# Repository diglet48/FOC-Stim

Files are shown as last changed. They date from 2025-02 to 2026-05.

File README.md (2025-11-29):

FOC-Stim is a family of next-generation estim devices that generate current-controlled analogue waveforms.
It can be controlled with [Restim](https://github.com/diglet48/restim).

Unlike traditional devices, the FOC-Stim has no channels
but offers an any-to-any output topology.

# Version 1

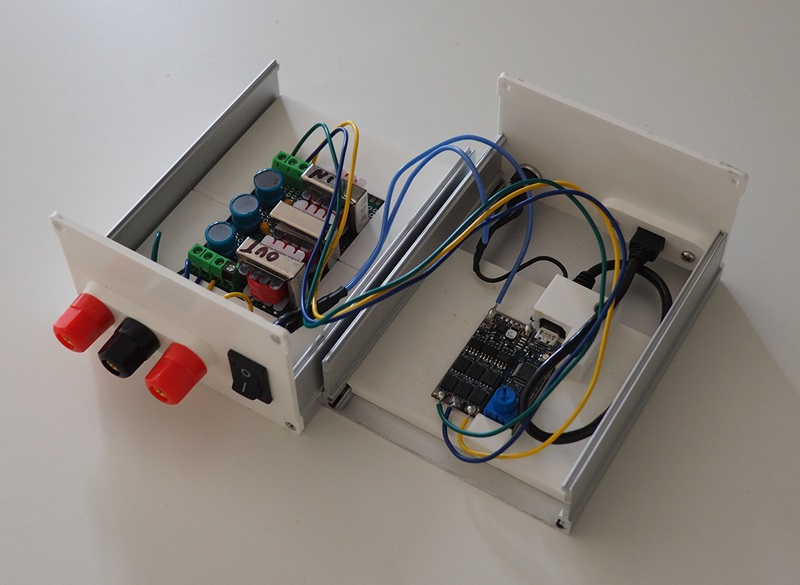
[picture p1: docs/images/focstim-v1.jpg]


Version 1 has 3 outputs. It uses a three-phase motor drive development kit from ST (the [B-G431B-ESC1](https://www.st.com/en/evaluation-tools/b-g431b-esc1.html)) for control. It only support three-phase output.

It is fairly easy to build with basic soldering skills, all parts can be ordered from mouser. For more information see [docs/focstim-v1.md](docs/focstim-v1.md)

# Version 4

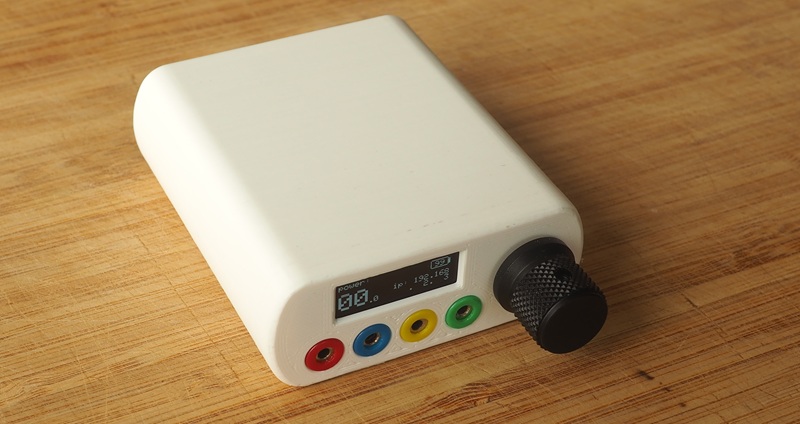
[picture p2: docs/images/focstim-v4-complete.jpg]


Version 4 uses a custom PCB. It improves the original by adding one extra output, a battery, and wireless comms.

See [docs/focstim-v4](docs/focstim-v4.md) for more info.

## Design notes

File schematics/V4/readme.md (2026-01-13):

You can order assembled boards from JLCPCB

## Mainboard
* Single-sided assembly (PCBA type standard, not economic)
* Select lead-free HASL finish.
* Verify the rotation of all chips and diodes against the reference image. The initial placement usually has U11 oriented wrongly. 

## Frontpanel
* Single-sided assembly (PCBA type economic) OR no assembly
* Select lead-free HASL finish.

You can choose to let JLCPCB assemble the SMD nuts and 2.0mm headers,
the error rate for letting users solder these components at home is
surprisingly high.

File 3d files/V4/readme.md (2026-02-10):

# Print instructions

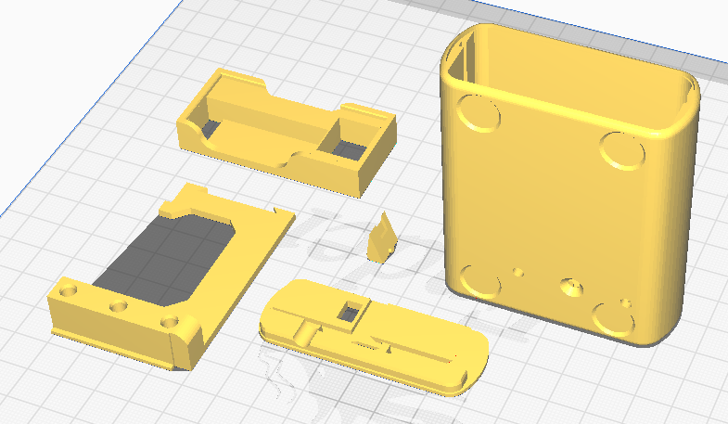
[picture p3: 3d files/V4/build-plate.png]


No supports needed when printing at 0.2mm layer height.

When printing the case, align seams on the bottom.

Rear panel with 0.0mm clearance is a snap fit on my printer.

Display spacer is optional in case you have problems with the display
bending, it can be jammed behind the display.

# Extra prints

`extras/switch clip` a clip designed to fit in the nintendo switch leg strap,
for wearing the device on your leg. Designed for M3x8 countersink.

`extras/rear panel exp` a modified rear panel with a cutout for 2x5 1.27mm connector,
can be used to break out the expansion header with a standard 10cm SWD cable.

# Changelog

* 10/02/2026 Increase PCB rail clearance from 0.2mm to 0.3mm
* 08/01/2026 Modified rear panel for V4.2 (1 capacitor moved)
* 29/11/2025 Initial release for V4.1 PCB

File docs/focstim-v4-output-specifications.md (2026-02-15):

# Introduction

The maximum output the FOC-Stim V4 can deliver depends on the skin resistance.

With which skin resistance can the device still blow your socks off?
The answer is approximately $500 \Omega$.

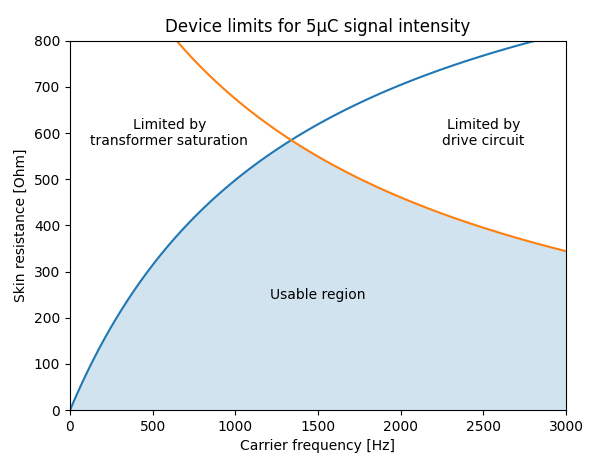
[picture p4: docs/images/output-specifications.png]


# Skin resistance?

I like using the skin resistance instead of the body resistance,
as the basic concept of body resistance starts to become fuzzy with more
than 2 electrodes. In most cases, skin resistance * 2 = body resistance.

I collected some data under various circumstances:

| skin resistance<br/>(one-way) | example |
|---:|---|
| 25 Ω | Large metal insertable |
| 50 Ω | Electro-rings (metal) |
| 100 Ω | Double-wrap of 8mm conductive rubber<br/>below balls |
| 140 Ω | Glans loop with 8mm conductive rubber,<br/> 3x3cm rubber pad |
| 200 Ω | Year-old rubber loops, regularly used |
| 250 Ω | Industry standard testing value,<br/> 3x3cm sticky pad |
| 500 Ω | ? |
| 1000 Ω | mystim brand conductive rubber insertables |

Most electrodes fall well within the usable region.

# Appendix

## Assumptions

The Xicon 42TL004 is limited to $`7500 V*\mu s`$ output before complete 
saturation, in practice $`6000 V*\mu s`$ is about the max for
undistorted waveforms. The winding ratio is 5.5.

The FOC-Stim V4 drive circuit is limited to $30V$. For technical
reasons, the effective voltage-to-neutral is a bit less than half that,
I use a conservative limit of $10V$. This results in an output-to-output
voltage of $110V$.

The maximum signal intensity I use is a bit less than $5\mu C$. 
I used this number as a benchmark.

The FOC V4 boost circuit can deliver about 4W of power. 
This is assumed to be not a limitation.

The device $\frac{dI}{dt}$, current sense range, control loop bandwidth
and transformer specifications all start to become problematic around
$3000Hz$ to $5000Hz$.

Time constant of the nerves is $355\mu s$

## Math

$Q_0 = 5 \mu C$, the maximum tolerable signal intensity.

$Q_t = Q_0 \times (1 + \dfrac{\text{pulsewidth}}{355\mu s})$, the amount of charge we 
actually have to deliver to get the maximum signal intensity.

$Q_t = \pm \dfrac{I_{\text{peak}}}{2 \times \pi \times \text{frequency}}$, minimum and maximum charge in sine wave signal.

$R = \dfrac{Vs}{Q_t}$, link transformer saturation to resistance and charge.

$R = \dfrac{10V \times \text{winding ratio}}{I_{\text{peak}}}$, ohms law assuming inductance is negligible. 

It follows that the maximum resistance before we run into 
transformer saturation is:

$R = \dfrac{6000V\mu s}{5\mu C \times (1 + \dfrac{1}{2 \times \text{frequency} \times 355\mu s})}$

And the maximum resistance before the drive circuit maxes out is:

$R = \dfrac{10V \times \text{winding ratio}}{5\mu C \times \pi \times (\text{frequency} \times 2 + \frac{1}{355\mu s})} - \text{drive circuit resistance}$

The drive circuit resistance is about $1.75 \Omega \times \text{winding ratio}^{2}$

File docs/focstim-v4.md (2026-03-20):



Schematics, PCB and case design by Sekizen.  
Software by Diglet.

# Specifications

* Three and four-phase output capability.
* 7-hour battery life with typical electrodes.
* Wireless communication (Wifi).
* Small display for diagnostics, knob for volume adjustments.
* Built-in accelerometer.
* Optional external sensors for nogasm/edge-o-matic functionality.

# Useful pages

* [Schematics / Gerbers](/schematics/V4/readme.md)
* [Bill of materials](focstim-v4-BOM.md)
* [3D files](/3d%20files/V4)
* [Assembly guide](focstim-v4-assembly.md)
* [Flashing your board](focstim-v4-flashing.md)
* [AS5311 sensor](as5311%20sensor.md)

# Nerd zone

* [Output specifications](focstim-v4-output-specifications.md)

# Changelog

## V4.3
Replace C6 (SYSSense) and C20 (VMSense) from 100nF to 10nF.  
Improve thermal relief on some hard-to-solder ground pads on mainboard and frontpanel.

## V4.2
Added LSM6DSOX 6-DOF IMU.  
Added cutout for ESP32 antenna.  
Change the part number of the boot buttons to save space.  
Change the part number of the boost inductor due to parts shortage.  
Add ground spokes to some solder pads.  
Modified board outline to reduce abrasion on frontpanel.

## V4.1
Initial public version.  
Changed most pin assignments on the ESP32.  
Adjust switch circuit to avoid inrush current killing the TSP631000.  
Modify frontpanel dimensions for extra creepage/clearance.  

## V4.0
Not publicly released, switched to DRV8231A drivers.

## V3.0
Not publicly released, based on MAX22213 drivers.

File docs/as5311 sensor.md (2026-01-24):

The FOC-Stim V4 has support for an erection sensor based on the AS5311.

Get the 3D files here: https://github.com/diglet48/toy-designs/tree/main/omega%20clamp

To construct this sensor and attach it to your FOC-Stim, you need these parts:

* modified rear panel [found in extras](/3d%20files/V4/readme.md).
* ams OSRAM AS5311-TS_EK_AB sensor board. 
* 3.3cm of magnet strip https://aliexpress.com/item/1005002805940724.html
* jtag breakout board https://aliexpress.com/item/1005004180810695.html
* 10cm 1.27mm 2x5 flatcable, for inside the box. https://aliexpress.com/item/1005008046702049.html
* 50cm 1.27mm 2x5 flatcable, male to female. https://aliexpress.com/item/1005006350473754.html
* 1.27mm 2x5 IDC header socket https://aliexpress.com/item/1005010396002233.html

# Build instructions

Embed your 10mm cable inside the rear panel like this. 
Inside the box, it will connect to the header marked "EXPD".

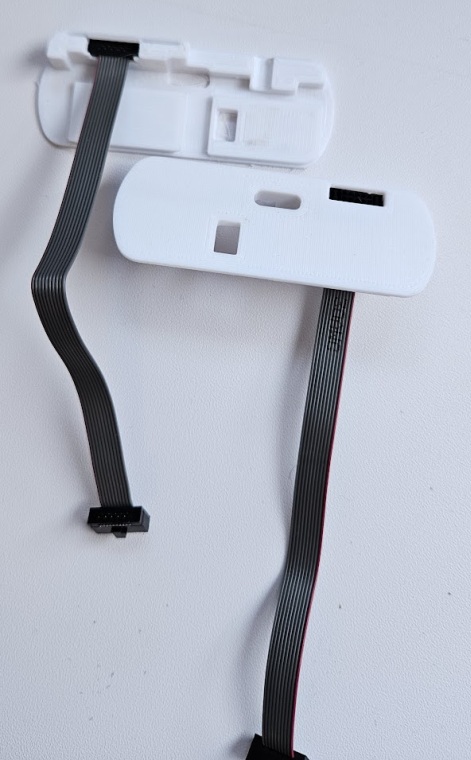
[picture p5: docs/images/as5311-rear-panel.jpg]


Cut off part of the 50cm flatcable and swap wires 1/2, 3/4, 5/6, 7/8, 9/10.
Then crimp on a new header.

This needs to be done because the male-to-female cable mirrors the pins. It
is not needed if you plug the sensor with a simple female-to-female cable
directly into the mainboard.

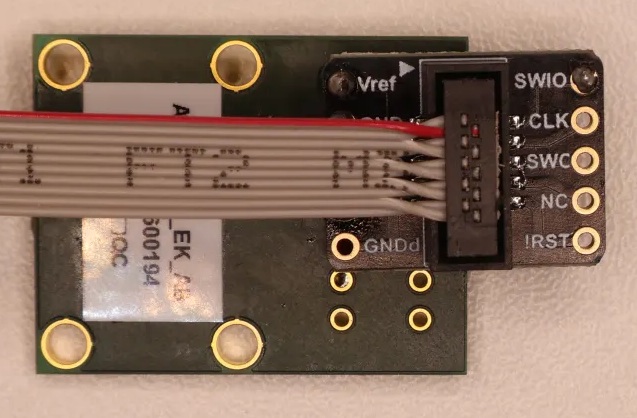
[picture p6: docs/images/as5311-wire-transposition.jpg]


Solder the breakout board with 4 2.54mm pins to the sensor.

Connect the line of (four) pins "vref, gnd, gnd, key" on the breakout board to
"gnd, DO, CLK, CSn" on the AS5311. Then use a small piece of wire to bridge
SWO to both 3v3 and 5v.

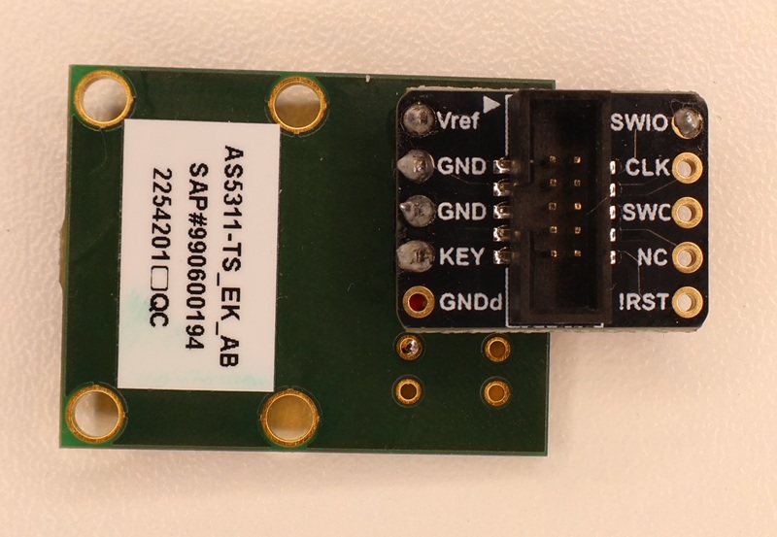
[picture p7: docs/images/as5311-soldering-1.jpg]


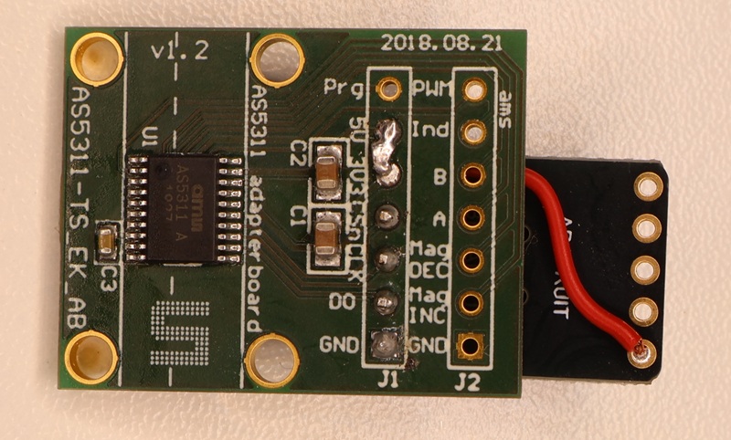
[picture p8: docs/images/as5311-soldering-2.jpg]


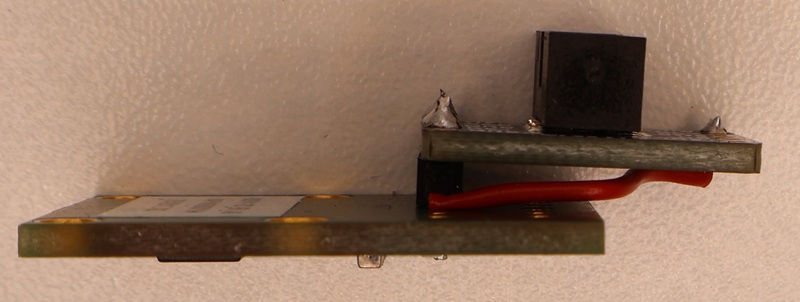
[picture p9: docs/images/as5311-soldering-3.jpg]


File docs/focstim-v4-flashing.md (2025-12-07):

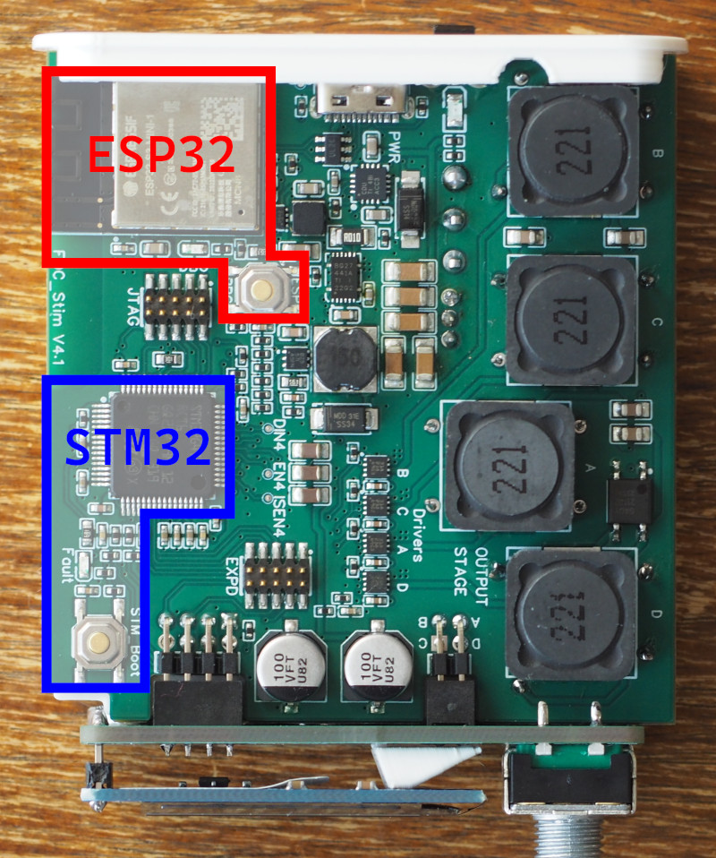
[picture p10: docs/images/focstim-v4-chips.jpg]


The FOC-Stim V4 contains 2 chips that need software to work, an ESP32 and STM32.

Only the switch is required to be soldered before flashing.

# The easy way

The first time flashing the board, you will need to hold the boot
button next to the respective chip while flipping the power switch.
This puts the chip in firmware update mode.

ESP32: Use the webflasher at https://github.com/diglet48/FOC-Stim-esp32-Webflasher

STM32: Start Restim, use tools -> firmware updater. Download firmware binary here: https://github.com/diglet48/FOC-Stim/releases

# Development

Development for both chips is done with Visual Studio Code.
Install the plugins PlatformIO and optionally Teleplot.

## ESP32

Get the code here: https://github.com/diglet48/FOC-Stim-esp32  
Make sure the correct environment is selected. (`focstim_v4_1` or `focstim_v4_0`).
Click the `upload` button in the sidebar.

V4.0 and V4.1 are not compatible.

## STM32

Get the code here: https://github.com/diglet48/FOC-Stim  
Make sure the correct environment is selected. (`focstim_v4`).

Use Restim or attach a debugger to upload the code to the board.

V4.0 and V4.1 use the same STM32 firmware.

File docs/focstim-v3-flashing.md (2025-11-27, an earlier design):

> [!CAUTION]
> Only applicable to FOC-Stim V3, not V4 or later.

# Soldering

* 4x transformers
* 4x 4mm bullet connectors (red, blue, yellow, green)
* 1x potmeter (optional)
* 1x jst-ph 2.0mm (optional, for battery. No reverse voltage protection!!!)

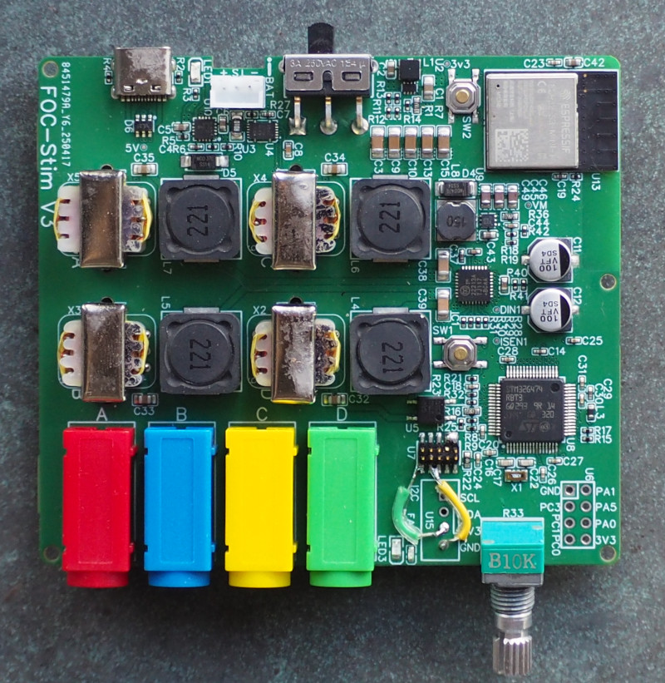
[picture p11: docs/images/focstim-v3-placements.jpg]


# Flashing the ESP32

All V3 boards I sent out came with the ESP32 firmware pre-programmed.

# Flashing the STM32 (serial)

Due to various hardware bugs, the STM32 crashes on boot. Extra steps are needed to boot normally or enter the bootloader.

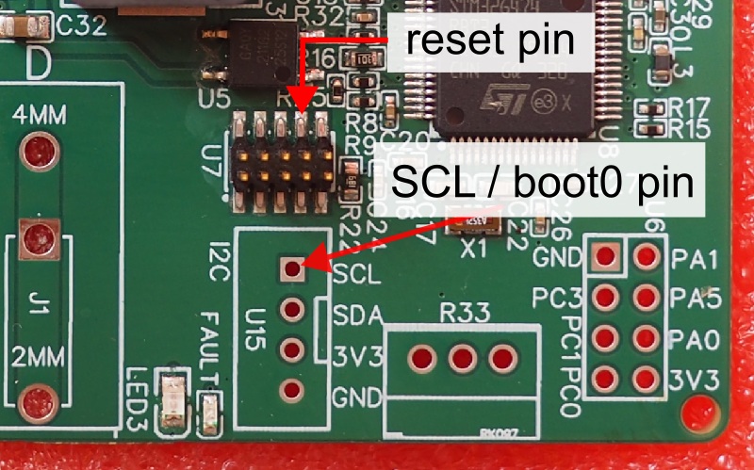
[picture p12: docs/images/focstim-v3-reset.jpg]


**To enter the bootloader:** turn on the power, then briefly short the reset pin to ground.

In the bootloader, the following actions can be performed with the STM32CubeProgrammer CLI:

Erase the flash: `.\STM32_Programmer_CLI.exe -c port=COM4 -e all`

Program the firmware: `.\STM32_Programmer_CLI.exe -c port=COM4 -d firmware.elf`
(`.hex` also works. `.bin` does not work)

Start the firmware: `.\STM32_Programmer_CLI.exe -c port=COM4 -g 0x08000000`

Using the GUI to program the board will often fail.

**To start the board:** short the SCL / Boot0 pin to ground before flipping the power switch. If done succesfully, one of the LEDs will turn on.

# Flashing the STM32 (jtag debugger)

Ensure your V3 board has the required patches.

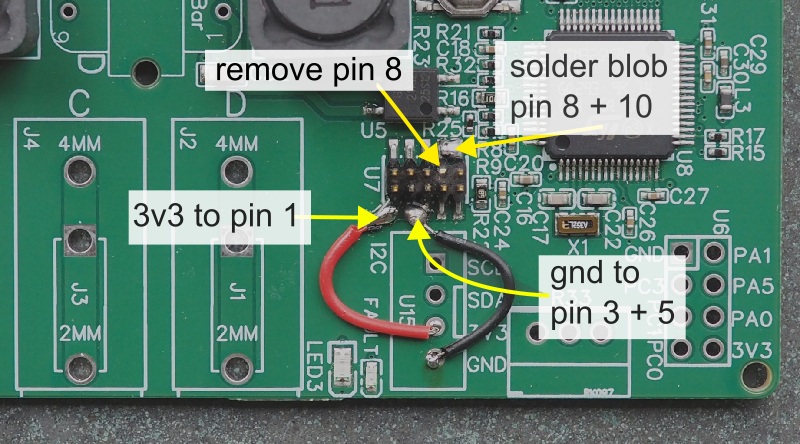
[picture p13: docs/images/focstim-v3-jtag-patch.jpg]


Upload the .elf firmware using your debug probe. I use segger J-Link with ozone debugger, but STM32CubeProgammer works too.

A hardware bug prevents the firmware from starting normally. Use one of these methods to start the firmware:
* Use the ozone debugger to 'reset program to main (F4)'.
* Short the SCL pin to ground, then reboot the board by shorting the reset pin or flip the power switch.
* Use STM32CubeProgrammer to set option bit `nSWBOOT` to 0. You can then boot the board normally. Only do this if you have a debug probe!

# Battery

To run the system from battery, the fuel gauge first needs to be programmed. The firmware does this on boot, provided you did not short SCL / Boot0 to ground.

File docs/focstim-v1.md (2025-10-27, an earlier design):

# Hardware

For component selection, refer to the [Bill of materials](/docs/focstim-v1-BOM.md).

How to wire:



`U`, `V`, `W` are the 3 outputs on the board, with `U` being the one closest to the potentiometer.

The side of the transformer marked with black sharpie should be connected to the board-side.
The primary, indicated with a "P", is the output side.

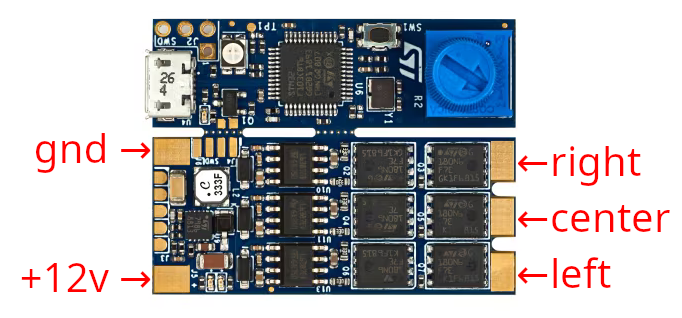
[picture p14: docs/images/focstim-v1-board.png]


The build on a breadboard:

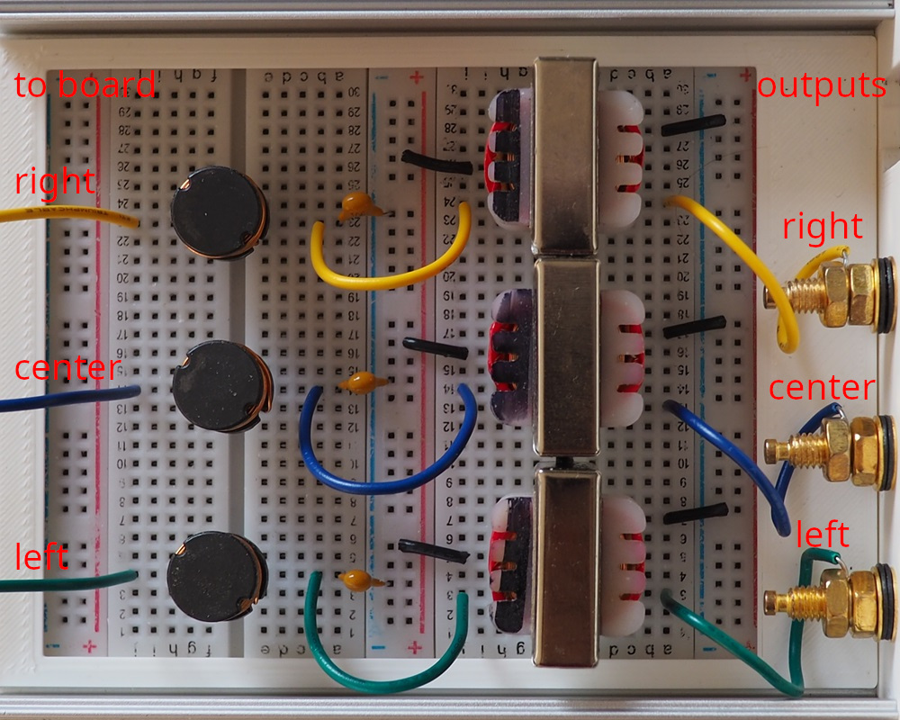
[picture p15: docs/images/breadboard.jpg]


Complete build built into 120x97x60mm aluminium enclosure.

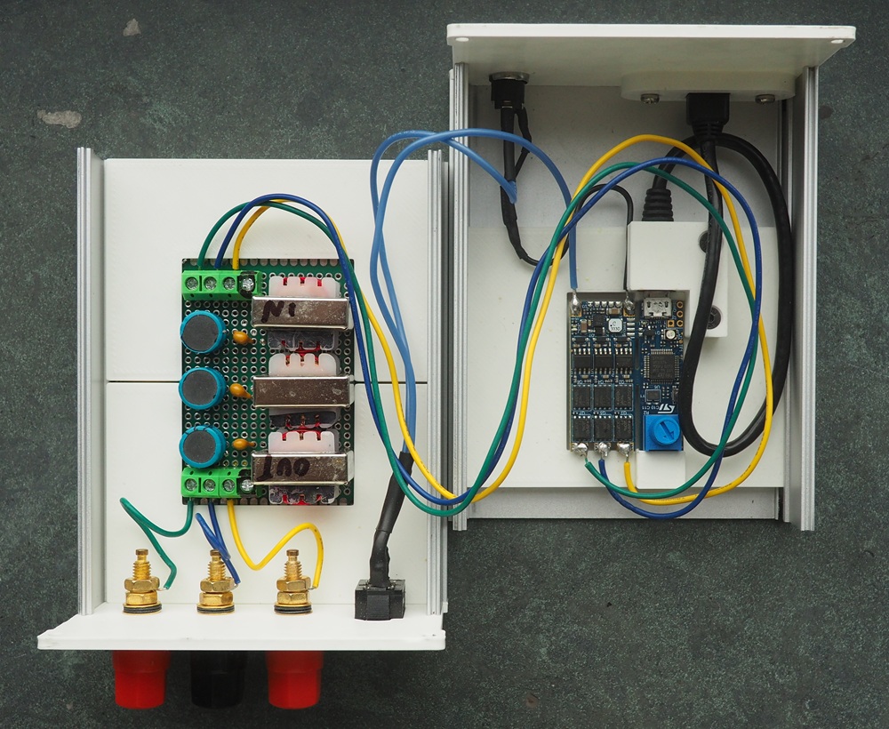
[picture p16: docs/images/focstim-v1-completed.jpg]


# Software

From the factory, the board has a very old ST-link firmware that prevents the usb-serial from working
correctly on some computers. It is highly recommended to update the ST-link firmware using
[STM32CubeProgrammer](https://www.st.com/en/development-tools/stm32cubeprog.html) before proceeding.

## Uploading firmware

Download the latest firmware binary from https://github.com/diglet48/FOC-Stim/releases (b_g431b_esc1_firmware.bin).
Use STM32CubeProgrammer to upload the firmware to the device.

## Build the firmware yourself

Install Visual Studio Code with plugins `platformio` and `teleplot`,
then build and upload the firmware, instructions below.

For this hardware, you must select project `env:disco_b_g431b_esc1`.



# Control

Control over USB with Restim.

View live stats with teleplot.

The onboard pot can be used to control the signal intensity.
If you only want to use software control, turn it all the way clockwise.
You can desolder the pot and use the pins to wire an external pot for your box.

All restim features are supported except: vibration.

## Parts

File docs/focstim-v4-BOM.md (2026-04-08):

# PCB

Mainboard from JLCPCB, one-sided assembly.  
Frontpanel from JLCPCB, one-sided assembly or bare PCB.  

# Mainboard components

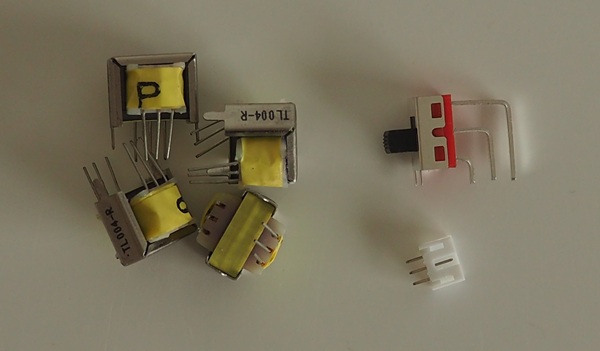
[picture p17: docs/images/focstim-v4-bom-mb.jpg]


### Transformer
4x Xicon 42TL004-RC. [Mouser](https://mouser.com/ProductDetail/Xicon/42TL004-RC?qs=%252BLh6ltJumVRX87vpOY3zCA%3D%3D)

Alternatives:
42TL004-RC on ebay, a knockoff without the xicon brand, but very close to the original.  
Xicon 42TL001-RC. 5-10% lower battery life, higher maximum power in some scenarios. Use the 42TL001 firmware.

### Switch
XKB Connection SS-12D28G5. [LCSC](https://www.lcsc.com/product-detail/C1121878.html)  
alternative part: SS-12D28L5  

### Battery connector
JST B3B-PH-K-S(LF)(SN) [LCSC](https://www.lcsc.com/product-detail/C131339.html), [Aliexpress](https://aliexpress.com/item/1005004393386300.html)

# Frontpanel components

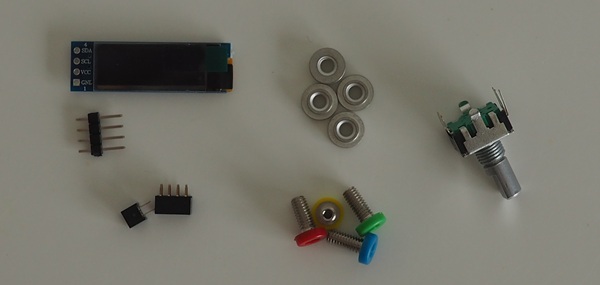
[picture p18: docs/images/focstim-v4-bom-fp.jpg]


### Display
HS HS91L02W2C01. [LCSC](https://www.lcsc.com/product-detail/C5248081.html)  
Alternative part: search for SSD1306 I2C 128x32 0.91 OLED Display. Make sure dimensions are 12x38mm, monochrome (1-color). Not recommended because every display has the actual display area in a slightly different spot. [Aliexpress](https://aliexpress.com/item/1005005301005280.html)

### 2.54mm 1x4 header, male
For the display. Cut off length that you need. [Alixpress](https://aliexpress.com/item/1005009749780893.html)

### 2.0mm 2x2 header, female
JLC can assemble the component for you.

[Aliexpress](https://aliexpress.com/item/1005006954403874.html)  
[LCSC](https://www.lcsc.com/product-detail/C18723064.html)  

### 2.0mm 2x4 header, female
JLC can assemble the component for you.

[Aliexpress](https://aliexpress.com/item/1005006954403874.html)  
[LCSC](https://www.lcsc.com/product-detail/C18723066.html)

### SMD nut
JLC can assemble the component for you.

Equivalent parts, pick one:  
4x SMTSO-M4-2ET [Aliexpress](https://aliexpress.com/item/1005003780208153.html)      
4x SMTSO-M4-2ET [Mouser](https://mouser.com/ProductDetail/PEM/SMTSO-M4-2ET?qs=l4Gc20tDgJJftsdplEey1w%3D%3D)  
4x SMTSOM420BTR [LCSC](https://www.lcsc.com/product-detail/C49236416.html)  
4x SMTSOM420STR [LCSC](https://www.lcsc.com/product-detail/C49236401.html)  

### 2mm banana jack with 4mm thread, 4 colors (red, blue, yellow, green)
[Aliexpress](https://aliexpress.com/item/1005006083045067.html),
[Aliexpress 2](https://aliexpress.com/item/1005008667160927.html)

The manufacturer is Changzhou Amass Electronics, product 24.106.1 (red)

Many sellers have been observed to randomly ship the blue jacks with
either M4 or M4 fine thread, even within the same bag. If this happens
reorder and pray they send you the correct thread pitch next time.
    
### Encoder
Bourns PEC11R-4015F-S0024 (metal shaft, button, no detents, 24 pos) [LCSC](https://www.lcsc.com/product-detail/C143789.html), [Mouser](https://mouser.com/ProductDetail/Bourns/PEC11R-4015F-S0024?qs=Zq5ylnUbLm4l0nvCUCX4Xw%3D%3D)

Alternatives:  
Bourns PEC12R-4020F-S0024 (plastic shaft, button, no detents, 24 pos) [LCSC](https://www.lcsc.com/product-detail/C22466590.html), [Mouser](https://mouser.com/ProductDetail/Bourns/PEC12R-4020F-S0024?qs=Zq5ylnUbLm43qafljSxq%252Bw%3D%3D)  
aliexpress knockoff: https://aliexpress.com/item/1005007798682136.html, 19mm. Open the pot and reverse the spring to eliminate detents before soldering. Not as smooth as the others.

The threads/nut on the pot are not used.
A pot with detents can be used, but I prefer the smooth ones due to the higher resolution.

# Misc

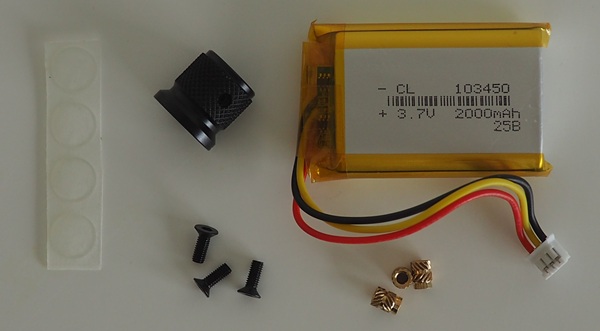
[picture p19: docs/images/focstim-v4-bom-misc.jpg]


### Encoder knob
My favorite: 
[Aliexpress](https://aliexpress.com/item/1005007470191877.html), 
[Aliexpress 2](https://aliexpress.com/item/1005007412387621.html),
[Aliexpress 3](https://aliexpress.com/item/1005008690035040.html)

Alternative style: [Aliexpress](https://aliexpress.com/item/1005007065833808.html)

6mm D-shaft. A knob with fairly aggressive knurling is required for one-finger operation. Max size approx 20mm.

### Non-slip feet

Round, 10mm diameter sticky feet
[Aliexpress](https://aliexpress.com/item/1005007646422189.html) (transparent) 
[Aliexpress 2](https://aliexpress.com/item/1005005667108142.html) (white or black)  

### M3 heatset insert
3x M3 heatset insert, designed for 4mm hole. Max length 6mm.

M3x6x4.5 [Aliexpress](https://aliexpress.com/item/1005004629314742.html), [Aliexpress 2](https://aliexpress.com/item/1005003582355741.html)  
M3x5.7 [CNC kitchen](https://cnckitchen.store/products/heat-set-insert-m3-x-5-7-100-pieces) (not tested)   
IUTB-M3 [Mouser](https://mouser.com/ProductDetail/SI/IUTB-M3?qs=7MVldsJ5Uay0LzKdLqXQgg%3D%3D) (not tested)  

### M3 screw

M3 countersink, length 4mm to 10mm. Optional accessories may require longer bolts.

TODO: sourcing link for this part

### Battery
A battery is optional.

34mm * 50mm. Maximum thickness 10mm. **Must be 3-pin JST-PH**.  
[Aliexpress](https://aliexpress.com/item/1005009218475835.html) slow shipping, [Aliexpress](https://aliexpress.com/item/1005003253170704.html) faster shipping,  
[ebay](https://www.ebay.com/itm/113697231078)  
[Amazon](https://www.amazon.com/dp/B09GKF5NQP) requires repin to JST-PH connector.  
Alternative: search for 303450, 403450, 503450, 603450, 703450, 803450, 903450, 103450

A 6mm 1200mAh battery lasts about 4 hours. 10mm 2000mAh about 7 hours.
By default, the software assumes you have a 2000mAh battery installed.

# Power supply

The FOC-Stim V4 takes power from a standard USB-C cable. A normal 5V / 500mA
port is sufficient for most use cases.

# Case

3D printed

# Cables

Pre-made cables:  
Colored 2mm to 2mm banana cables. [Aliexpress](https://aliexpress.com/item/1005009474228825.html)  
Colored 2mm to 2mm banana, stackable. [Aliexpress](https://aliexpress.com/item/1005009284748694.html)

Supplies for making your own cables if desired:  
Colored 2mm banana connectors: [Aliexpress](https://aliexpress.com/item/1005005307850027.html), [Aliexpress 2](https://aliexpress.com/item/1005005914150447.html)  
Colored 2mm TENS connectors: [Aliexpress](https://aliexpress.com/item/1005006066453610.html)  
AWG 20 cable fits perfectly in these jacks and is quite sturdy.

other useful parts:  
4mm to 2mm banana adapter: [Aliexpress](https://aliexpress.com/item/1005005565867054.html), [Aliexpress 2](https://aliexpress.com/item/1005009690976598.html)  
2mm to 4mm banana adapter: [Aliexpress](https://aliexpress.com/item/1005009682438992.html)

TODO: low-profile solution for electrodes with 4mm connector

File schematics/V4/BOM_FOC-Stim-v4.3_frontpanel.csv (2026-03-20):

ID | Name | Designator | Footprint | Quantity | Manufacturer Part | Manufacturer | Supplier | Supplier Part | Price
1 | PEC12R-4020F-S0024 | U7 | SW-TH_PEC12R-4020F-S0024FOCSTIMTRIMMED | 1 | PEC12R-4020F-S0024 | BOURNS | LCSC | C22466590 | 0.772
2 | 2005FV-2X4P | H2 | HDR-TH_8P-P2.00-V-F-R2-C4-S2.00-1 | 1 | 2005FV-2x4P | HanElectricity(瀚源) | LCSC | C18723066 | 0.09
3 | SMTSO4020CTJ - Modified for 1 pin | U3,U4,U5,U6 | SMD_BD8.7-D6.2 | 4 | SMTSO4020CTJ | Sinhoo(雄和远景) | LCSC | C2916374 | 0.133
4 | 2005FV-2X2P | U2 | HDR-TH_4P-P2.00-V-F-R2-C2-S2.00 | 1 | 2005FV-2x2P | HanElectricity(瀚源) | LCSC | C18723064 | 0.088

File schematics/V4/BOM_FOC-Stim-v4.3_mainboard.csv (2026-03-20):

ID | Name | Designator | Footprint | Quantity | Manufacturer Part | Manufacturer | Supplier | Supplier Part | Price
1 | 42TL004 | TR1,TR2,TR3,TR4 | 42TLMODIFIED | 4
2 | SS-12D28G5 | SW1 | SW-TH_SS-12D28G5 | 1 | SS-12D28G5 | XKB Connectivity(中国星坤) | LCSC | C1121878 | 0.73
3 | 10nF | C6,C20,C44,C45,C32 | C0402 | 5 | CL05B103KB5NNNC | SAMSUNG(三星) | LCSC | C15195 | 0.002
4 | 100uF | C18,C19 | CAP-SMD_BD6.3-L6.6-W6.6-FD | 2 | EEEFT1V101AP | PANASONIC(松下) | LCSC | C128464 | 0.259
5 | 10kΩ | R40,R11,R30,R36,R37,R38,R16,R25 | R0402 | 8 | 0402WGF1002TCE | UNI-ROYAL(厚声) | LCSC | C25744 | 0.001
6 | BQ27441DRZR-G1A | U4 | SON-12_L4.0-W2.5-P0.40-BL-EP COPY | 1 | BQ27441DRZR-G1A | TI(德州仪器) | LCSC | C473397 | 2.618
7 | 100kΩ | R2,R3,R9,R39,R10,R28,R7,R13 | R0402 | 8 | 0402WGF1003TCE | UNI-ROYAL(厚声) | LCSC | C25741 | 0.001
8 | 56kΩ | R4,R20 | R0603 | 2 | 0603WAF5602T5E | UNI-ROYAL(厚声) | LCSC | C23206 | 0.001
9 | 300Ω | R32 | R0603 | 1 | 0603WAF3000T5E | UNI-ROYAL(厚声) | LCSC | C23025 | 0.001
10 | 15uH | L2 | IND-SMD_L6.0-W6.0 | 1 | SMNR6045-150MT | SXN(顺翔诺) | LCSC | C467142 | 0.093
11 | 100nF | C23,C25,C26,C27,C28,C31,C34,C35,C47,C48 | C0402 | 10 | CL05B104KO5NNNC | SAMSUNG(三星) | LCSC | C1525 | 0.001
12 | TS-1088-AR02016 | SW2,SW3 | SW-SMD_L3.9-W3.0-P4.45 | 2 | TS-1088-AR02016 | XUNPU(讯普) | LCSC | C720477 | 0.054
13 | LSM6DSOXTR | U15 | LGA-14L_L3.0-W2.5-P0.50-TL | 1 | LSM6DSOXTR | ST(意法半导体) | LCSC | C481766 | 2.504
14 | 2.2uF | C36,C37,C39,C38 | C0805 | 4 | CL21A225KBQNNNE | SAMSUNG(三星) | LCSC | C377773 | 0.018
15 | 1nF | C46 | C0402 | 1 | 0402B102K500NT | FH(风华) | LCSC | C1523 | 0.001
16 | 1.5kΩ | R6,R27,R8,R12 | R0402 | 4 | 0402WGF1501TCE | UNI-ROYAL(厚声) | LCSC | C25867 | 0.001
17 | 22uF | C24,C3 | C0603 | 2 | CL10A226MQ8NRNC | SAMSUNG(三星) | LCSC | C59461 | 0.009
18 | KT-0603R | LED2,LED3 | LED0603-RD | 2 | KT-0603R | KENTO | LCSC | C2286 | 0.007
19 | 1kΩ | R26,R41,R31,R33,R34,R35 | R0402 | 6 | 0402WGF1001TCE | UNI-ROYAL(厚声) | LCSC | C11702 | 0.001
20 | 1uF | C1,C12,C29,C30,C33 | C0402 | 5 | CL05A105KA5NQNC | SAMSUNG(三星) | LCSC | C52923 | 0.004
21 | 100uF | C5,C10,C7,C8,C11 | C1206 | 5 | CL31A107MQHNNNE | SAMSUNG(三星) | LCSC | C15008 | 0.061
22 | 33kΩ | R22 | R0402 | 1 | 0402WGF3302TCE | UNI-ROYAL(厚声) | LCSC | C25779 | 0.001
23 | 47kΩ | R24,R21 | R0402 | 2 | 0402WGF4702TCE | UNI-ROYAL(厚声) | LCSC | C25792 | 0.001
24 | 17-21SUYC/TR8 | LED1 | LED0805-R-RD | 1 | KT-0805黄灯 | KENTO | LCSC | C2296 | 0.012
25 | STM32G473RCT6 | U6 | LQFP-64_L10.0-W10.0-P0.50-LS12.0-BL | 1 | STM32G473RCT6 | ST(意法半导体) | LCSC | C529361 | 3.655
26 | ESP32-S3-MINI-1-N8 | U7 | BULETM-SMD_ESP32-S3-MINI-1-N8 | 1 | ESP32-S3-MINI-1-N8 | ESPRESSIF(乐鑫) | LCSC | C2913206 | 4.632
27 | 20021121-00010T4LF | U8,U9 | HDR-SMD_10P-P1.27-V-M-R2-C5-S1.27-LS5.5 | 2 | 20021121-00010T4LF | Amphenol | LCSC | C598540 | 0.842
28 | 200kΩ | R17 | R0402 | 1 | 0402WGF2003TCE | UNI-ROYAL(厚声) | LCSC | C25764 | 0.001
29 | 20kΩ | R19 | R0402 | 1 | 0402WGF2002TCE | UNI-ROYAL(厚声) | LCSC | C25765 | 0.001
30 | 22nF | C21 | C0402 | 1 | 0402B223K500NT | FH(风华) | LCSC | C1532 | 0.002
31 | 100nF | C40,C41,C42,C43 | C0402 | 4 | CL05B104KB54PNC | SAMSUNG(三星) | LCSC | C307331 | 0.004
32 | 10uF | C2,C9,C14 | C0603 | 3 | CL10A106KP8NNNC | SAMSUNG(三星) | LCSC | C19702 | 0.007
33 | 470nF | C13 | C0603 | 1 | CL10B474KA8NNNC | SAMSUNG(三星) | LCSC | C1623 | 0.008
34 | 47uF | C4 | C0805 | 1 | CL21A476MQYNNNE | SAMSUNG(三星) | LCSC | C16780 | 0.036
35 | 10uF | C15,C16,C17 | C0805 | 3 | GRM21BR61H106KE43L | muRata(村田) | LCSC | C440198 | 0.072
36 | USBLC6-2SC6 | D1 | SOT-23-6_L2.9-W1.6-P0.95-LS2.8-BL | 1 | USBLC6-2SC6 | ST(意法半导体) | LCSC | C7519 | 0.139
37 | SS14 | D2 | SMA_L4.2-W2.6-LS5.3-RD | 1 | SS14 | MDD(辰达半导体) | LCSC | C2480 | 0.017
38 | SS34_C8678 | D3 | SMA_L4.3-W2.6-LS5.2-RD | 1 | SS34 | MDD(辰达半导体) | LCSC | C8678 | 0.03
39 | 2005WR-2X4P | H1 | HDR-TH_8P-P2.00-H-F-R2-C2-S2.00-W8.8 | 1 | 2005WR-2x4P | HanElectricity(瀚源) | LCSC | C6837622 | 0.061
40 | 2005WR-2X2P | H2 | HDR-TH_4P-P2.00-H-M-R2-C2-W9.5 | 1 | 2005WR-2x2P | HanElectricity(瀚源) | LCSC | C6837620 | 0.035
41 | 1uH | L1 | IND-SMD_L3.0-W3.0_FTC303020D | 1 | FTC303020D1R0MBCA | cjiang(长江微电) | LCSC | C7423316 | 0.373
42 | 220uH | L3,L4,L5,L6 | IND-SMD_L12.3-W12.3_SMDRI127 | 4 | SMDRI127-221MT | SXN(顺翔诺) | LCSC | C10151 | 0.22
43 | 5.1kΩ | R1,R5 | R0402 | 2 | 0402WGF5101TCE | UNI-ROYAL(厚声) | LCSC | C25905 | 0.001
44 | 4.7kΩ | R15,R14 | R0402 | 2 | 0402WGF4701TCE | UNI-ROYAL(厚声) | LCSC | C25900 | 0.001
45 | 22kΩ | R23 | R0402 | 1 | 0402WGF2202TCE | UNI-ROYAL(厚声) | LCSC | C25768 | 0.001
46 | 680Ω | R29 | R0603 | 1 | 0603WAF6800T5E | UNI-ROYAL(厚声) | LCSC | C23228 | 0.001
47 | TPS631000DRLR | U1 | SOT-583-8_L2.1-W1.2-P0.50-LS1.6-BL | 1 | TPS631000DRLR | TI(德州仪器) | LCSC | C5219190 | 0.506
48 | BQ24075RGTR | U2 | QFN-16_L3.0-W3.0-P0.50-TL-EP1.7 | 1 | BQ24075RGTR | TI(德州仪器) | LCSC | C15464 | 1.043
49 | 10mΩ | U3 | R1206 | 1 | FRM121WFR010TM | FOJAN(富捷) | LCSC | C7467248 | 0.028
50 | TPS61170DRVR | U5 | QFN-6_L2.0-W2.0-P0.65-TL-EP | 1 | TPS61170DRVR | TI(德州仪器) | LCSC | C15163 | 0.596
51 | DRV8231ADSGR | U10,U12,U13,U14 | WSON-8_L2.0-W2.0-P0.50-BL-EP_DSG | 4 | DRV8231ADSGR | TI(德州仪器) | LCSC | C5139865 | 1.588
52 | GAQY211G2S | U11 | SOP-4_L4.4-W4.0-P2.54-LS7.0-TL | 1 | GAQY211G2S | SUPSiC(国晶微半导体) | LCSC | C7435104 | 0.929
53 | TYPE-C-31-M-12 FU | USBC | USB-C_SMD-TYPE-C-31-M-12 | 1 | TYPE-C-31-M-12 | 韩国韩荣 | LCSC | C165948 | 0.184
54 | 4.7uF | C22 | C0402 | 1 | CL05A475MP5NRNC | SAMSUNG(三星) | LCSC | C23733 | 0.005
55 | 1MΩ | R18 | R0402 | 1 | 0402WGF1004TCE | UNI-ROYAL(厚声) | LCSC | C26083 | 0.001

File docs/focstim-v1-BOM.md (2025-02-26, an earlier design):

# Core parts:

Ordering on mouser is recommended because the transformer is very difficult to find elsewhere.

* 1x Control board
  * B-G431B-ESC1 [mouser](https://mouser.com/ProductDetail/STMicroelectronics/B-G431B-ESC1?qs=%252B6g0mu59x7KUfhaFDGurZQ%3D%3D)

* 3x transformer
  * xicon 42TU200-RC [mouser](https://mouser.com/ProductDetail/42TU200-RC)
  * If not in stock, 42TU400-RC can be used as a substitute.
  * If neither are available, look for audio transformers with winding ratio around 10, secondary resistance as low as possible. For safety, it is important not to choose transformers that are significantly larger than the xicon parts.

* 3x inductor
  * Fastron 09HCP-221M or 09HVP-221M [mouser](https://mouser.com/ProductDetail/Fastron/09HCP-221M-50?qs=igiTrb5Y5PMDjMomTeh8Hg%3D%3D)
  * Kemet SBCP-11HY221H. 80HY or 14HY series also possible [mouser](https://mouser.com/ProductDetail/KEMET/SBCP-11HY221H?qs=pfd5qewlna6%252BrMZ%252BQtyB1g%3D%3D)
  * Coilcraft RFB1010-221L [mouser](https://mouser.com/ProductDetail/Coilcraft/RFB1010-221L?qs=ZYnrCdKdyecpj3R4Spi0Qw%3D%3D)
  * Coilcraft RFS1317-224KL [mouser](https://mouser.com/ProductDetail/Coilcraft/RFS1317-224KL?qs=W38ilblRkRlSN%2FG2x%2FRvWA%3D%3D)
  * If neither are available, look for: inductance 180-470µH (220µH preferred), saturation current 0.8A minimum 1.3A preferred, flat inductance-current curve in the datasheet.

* 3x capacitor
  * FG18X5R1E106MRT06 [mouser](https://mouser.com/ProductDetail/TDK/FG18X5R1E106MRT06?qs=LtAzLad%252BoeWpVdbzeG4%252B8Q%3D%3D)
  * Many other options available. Must be ceramic, look for 4.7µF-10µF (10µF preferred), >25v

# Misc parts

Easy to find locally. You might not need all of these components.

* power supply
  * 12v 0.5A minimum, 1A preferred.
  * Most common is DC barrel jack, 5.5 x 2.1 mm.
  * A double-insulated power supply (two squares symbol) is highly recommended for safety.
  * For most users a voltage above 12v is excessive, but the board can be powered with a higher voltage if you need more power. Minimum voltage is 10v.

* DC barrel jack
  * Kubiconn 163-MJ22-EX [mouser search](https://eu.mouser.com/c/connectors/power-connectors/dc-power-connectors/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)

* Power switch
  * part ???

* Linear potmeter, 10k
  * Original pot on the board has to be removed.
  * Bourns PDB181-E420K-103B [mouser](https://mouser.com/ProductDetail/Bourns/PDB181-E420K-103B?qs=Ivs1Be2ZGq51QiDv8T3bpQ%3D%3D)
  * Davies Molding 1106WA [mouser](https://mouser.com/ProductDetail/Davies-Molding/1106WA?qs=byeeYqUIh0OqaUB%252BH6OtrA%3D%3D)

* USB micro-B cable
  * You probably already have one

* USB micro-B panel mount
  * SparkFun CAB-15464 [mouser](https://mouser.com/ProductDetail/SparkFun/CAB-15464?qs=XeJtXLiO41TW%252BnYEDtaNzg%3D%3D)
  * iJiZuo USB C to Micro USB Adapter [amazon](https://www.amazon.de/-/en/gp/product/B0B7RMFMN4/)

* general soldering supplies
  * Soldering iron
  * bunch of cable 1A rated, such as 20AWG.
  * protoboard such as Adafruit 2670 [mouser](https://mouser.com/ProductDetail/Adafruit/2670?qs=XAKIUOoRPe7ATe8H6FaFPg%3D%3D)

* Electrode connectors
  * My preference is 3x 4mm banana connectors, but some use a single 3.5mm audio jack.
  * Banana connectors: mouser calls these "Test Sockets 4MM"
  * audio jack: [mouser](https://mouser.com/ProductDetail/Same-Sky/SJ5-43502PM?qs=WyjlAZoYn52%252BIiPG9eebPg%3D%3D), [mouser](https://mouser.com/ProductDetail/Adam-Tech/ASJ-165-M-G-HDW-1?qs=HoCaDK9Nz5db8cIJnMDZYw%3D%3D)

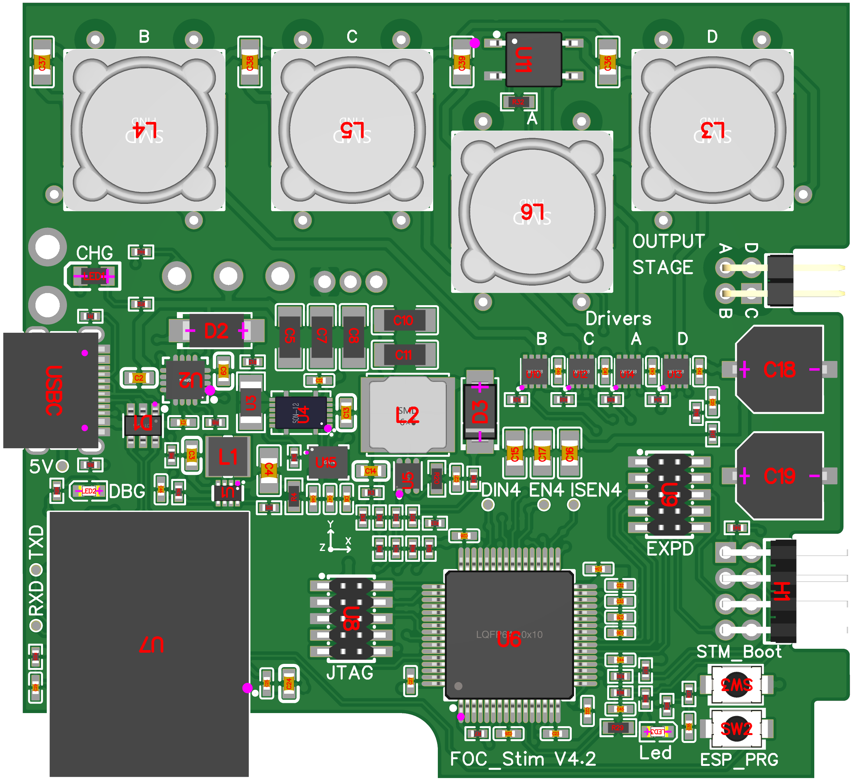
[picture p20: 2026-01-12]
schematics/V4/component_placement.png

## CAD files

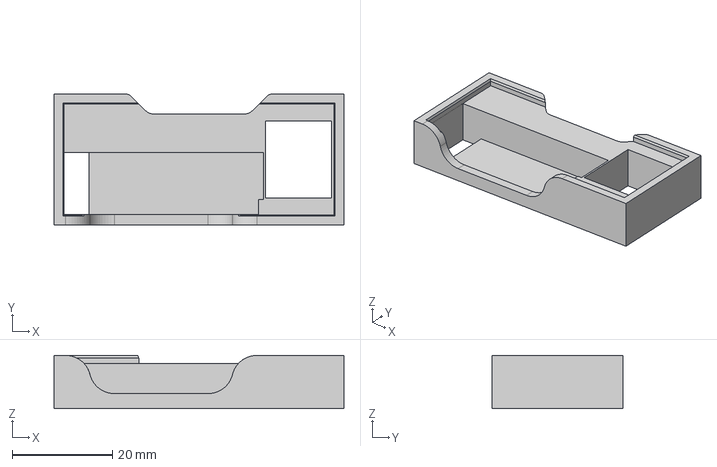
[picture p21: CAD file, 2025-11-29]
3d files/V4/assembly fixture.step
57.8 x 26.2 x 10.6 mm

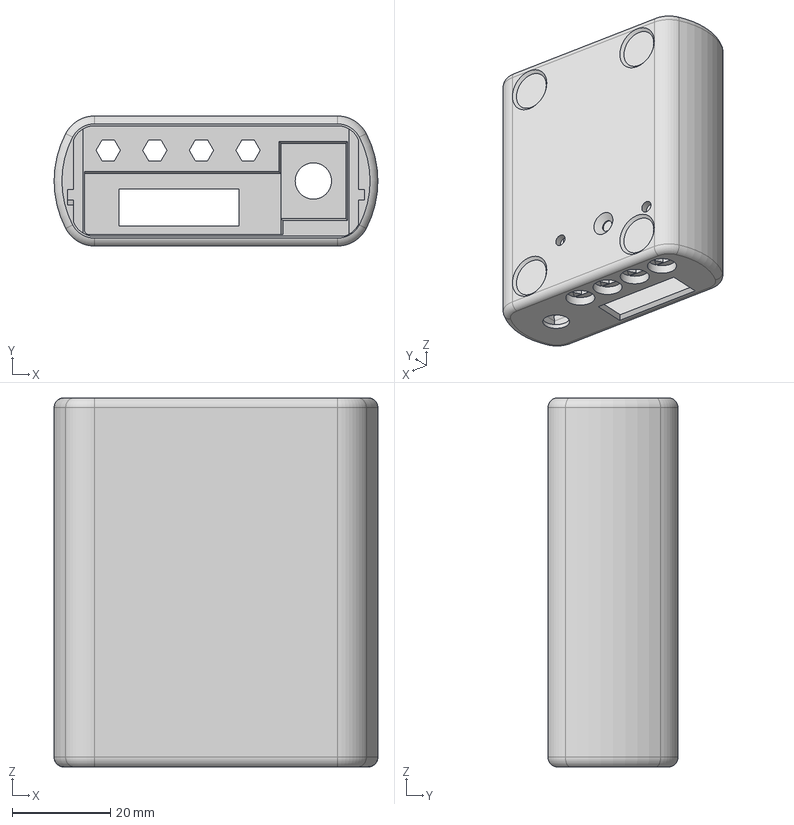
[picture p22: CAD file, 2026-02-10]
3d files/V4/case.step
66.0 x 26.5 x 75.2 mm

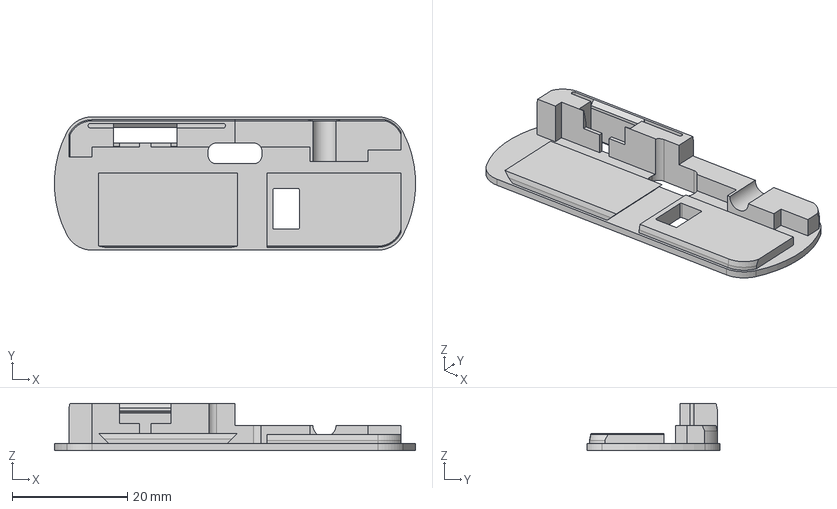
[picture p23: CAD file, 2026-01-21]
3d files/V4/extras/rear panel exp - 0.1mm clearance.step
62.5 x 23.1 x 8.20 mm

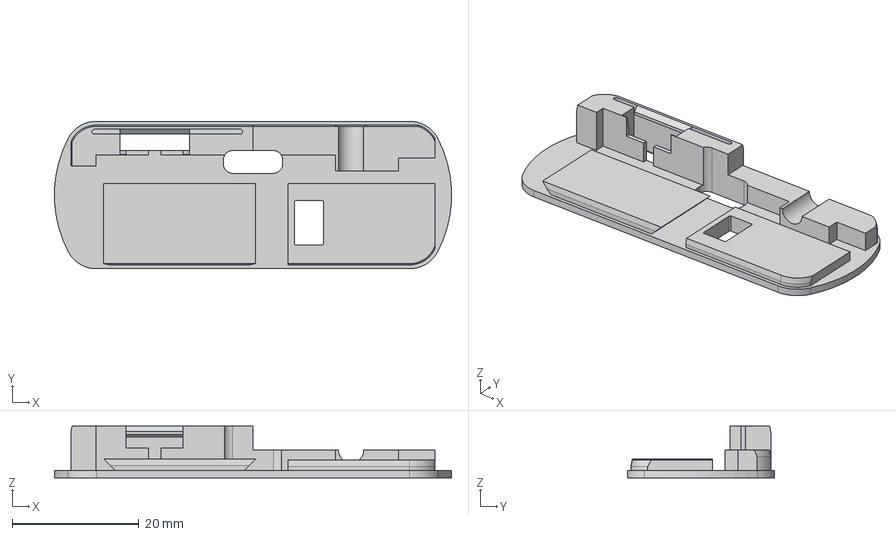
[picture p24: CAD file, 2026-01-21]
3d files/V4/extras/rear panel exp - 0.0mm clearance.step
62.7 x 23.3 x 8.20 mm

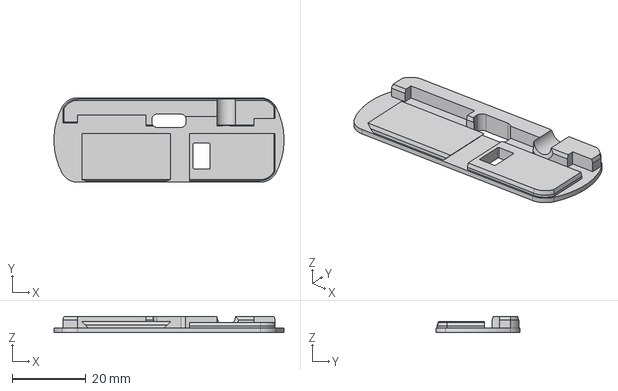
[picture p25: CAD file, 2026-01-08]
3d files/V4/rear panel - 0.2mm clearance.step
62.3 x 22.9 x 4.40 mm

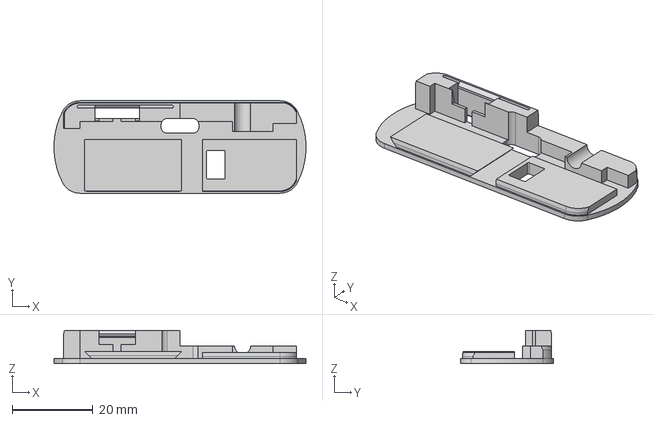
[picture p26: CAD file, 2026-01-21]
3d files/V4/extras/rear panel exp - 0.2mm clearance.step
62.3 x 22.9 x 8.20 mm

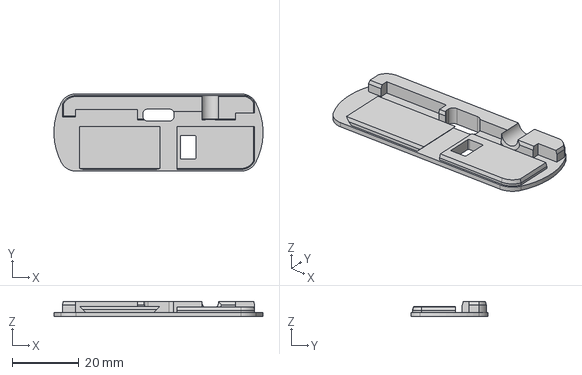
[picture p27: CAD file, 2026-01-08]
3d files/V4/rear panel - 0.1mm clearance.step
62.5 x 23.1 x 4.40 mm

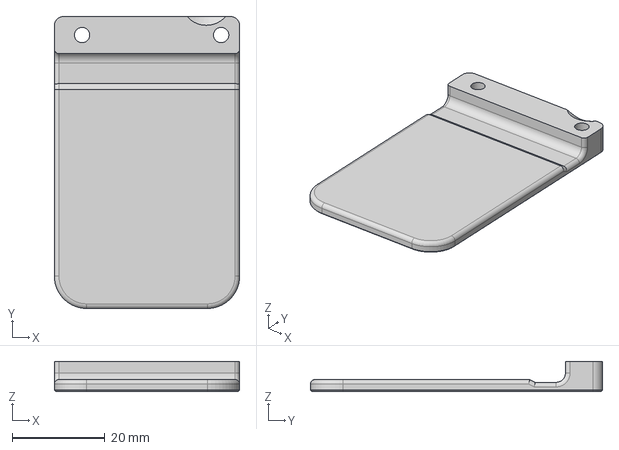
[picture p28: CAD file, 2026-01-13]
3d files/V4/extras/switch clip.step
40.0 x 63.0 x 6.50 mm

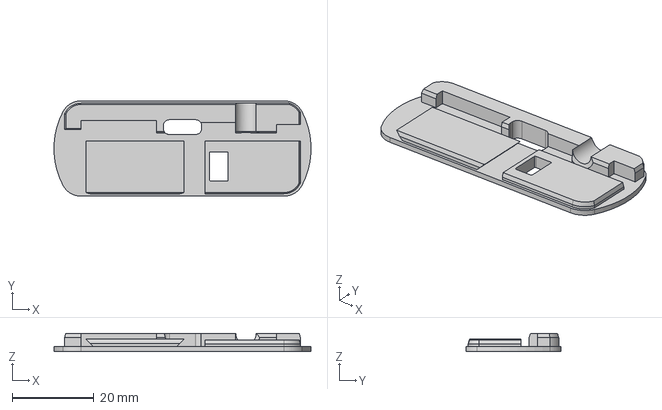
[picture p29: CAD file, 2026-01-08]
3d files/V4/rear panel - 0.0mm clearance.step
62.7 x 23.3 x 4.40 mm

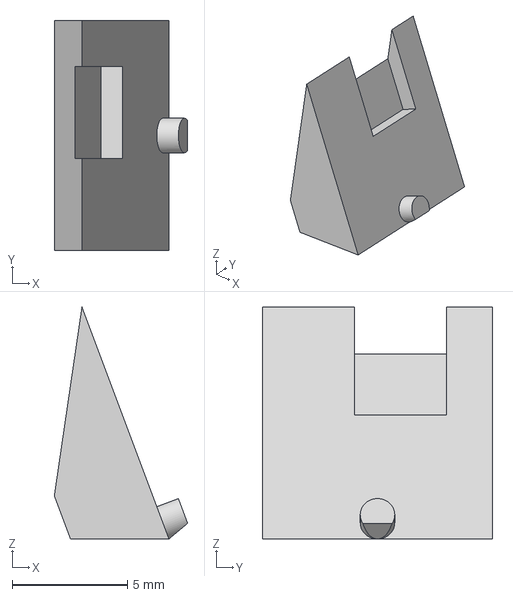
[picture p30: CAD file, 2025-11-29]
3d files/V4/display spacer.step
5.79 x 10.0 x 10.1 mm

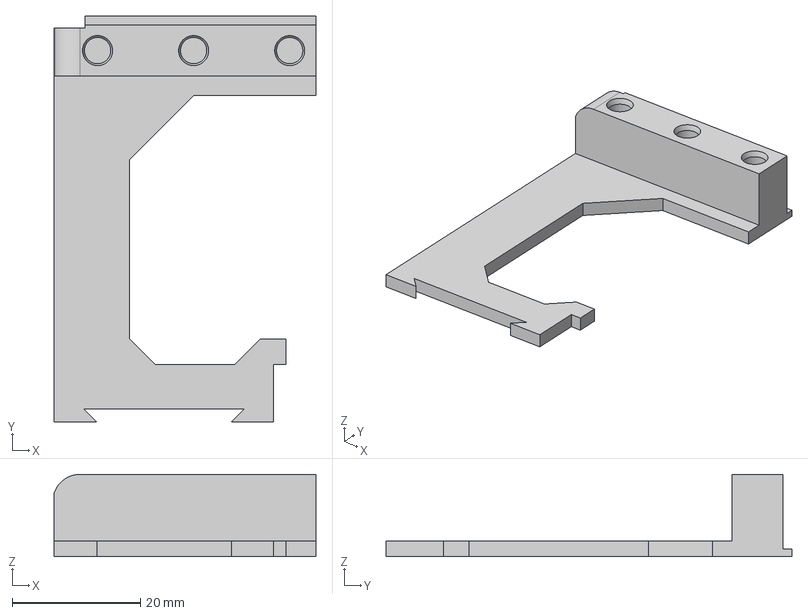
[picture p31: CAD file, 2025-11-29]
3d files/V4/battery sled.step
40.9 x 63.4 x 12.9 mm

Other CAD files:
3d files/V4/assembly fixture.stl
3d files/V4/battery sled.stl
3d files/V4/case.stl
3d files/V4/display spacer.stl
3d files/V4/extras/rear panel exp - 0.0mm clearance.stl
3d files/V4/extras/rear panel exp - 0.1mm clearance.stl
3d files/V4/extras/rear panel exp - 0.2mm clearance.stl
3d files/V4/extras/switch clip.stl
3d files/V4/rear panel - 0.0mm clearance.stl
3d files/V4/rear panel - 0.1mm clearance.stl
3d files/V4/rear panel - 0.2mm clearance.stl

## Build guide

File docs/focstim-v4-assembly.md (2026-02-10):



# Mainboard

Break off all the side rails, you can use some sandpaper to remove the sharp edges.

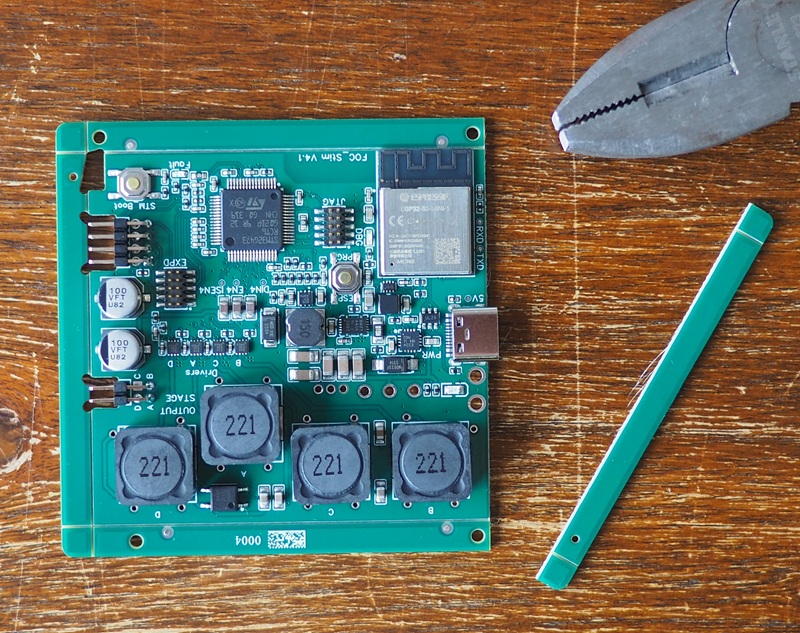
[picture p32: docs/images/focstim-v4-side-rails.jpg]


Snip off the middle pins of the 4 transformers, bend the metal tabs in.

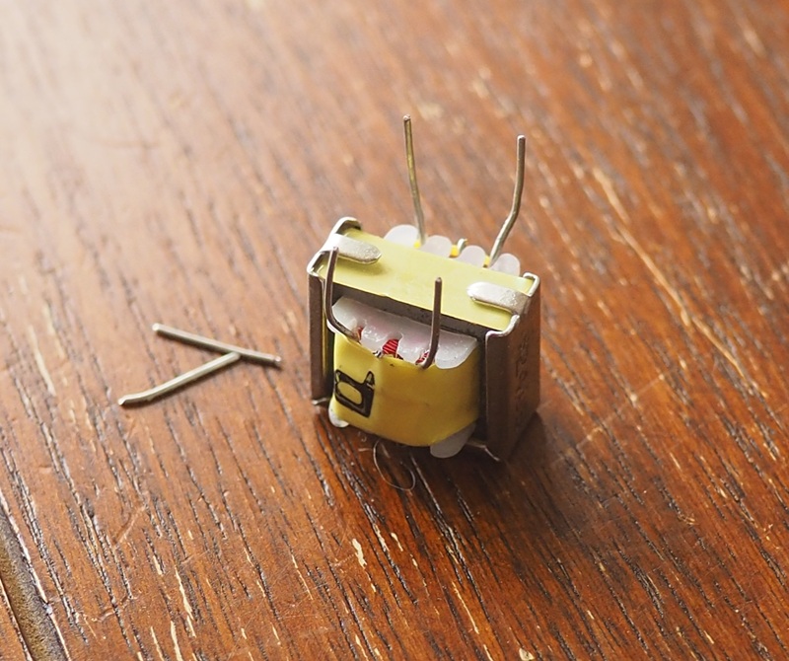
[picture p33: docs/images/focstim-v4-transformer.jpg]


Solder the transformers to the unpopulated side of the board, 
you have to bend the pins to fit into the holes.

The orientation is important! The genuine Xicon 42TL004 are clearly marked
with a 'P' and black sharpie mark on top.

With other transformers, the low-voltage side (1 ohm) is on the inside,
and the high-voltage side (10-40 ohm) is on the edge of the board.
The high-voltage side goes directly to the 4-pin on the frontpanel.

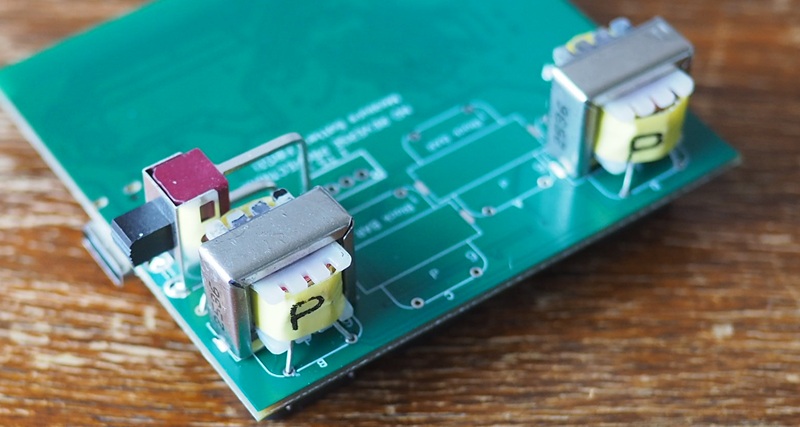
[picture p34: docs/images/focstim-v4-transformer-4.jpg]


Solder the battery connector and switch to the unpopulated side of the board.

> [!CAUTION]
> Not all batteries have the same pinout. Connecting a battery with the wrong pinout will
> destroy your board.
> 
> The correct orientation of the battery connector depends on your battery pinout,
> compare your battery with the `+ -` printed on the PCB. 
> The image shows the most common pinout.

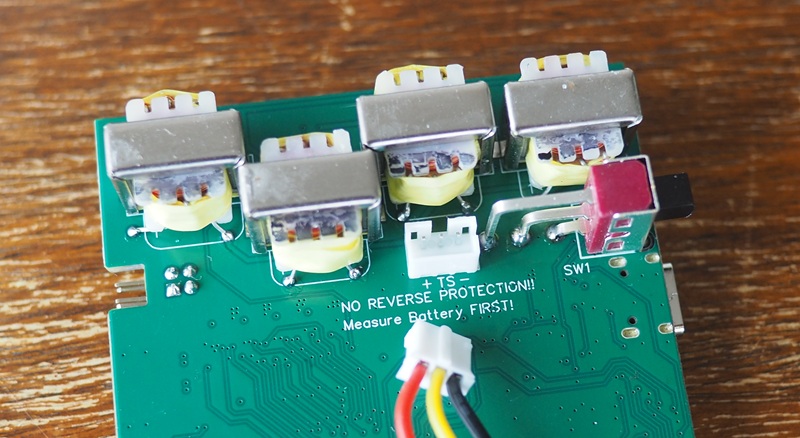
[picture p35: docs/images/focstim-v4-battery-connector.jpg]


# Frontpanel

> [!NOTE]  
> Make sure to solder the frontpanel components to the correct side

> [!NOTE]  
> Follow this assembly order

> [!NOTE]
> JLC can assemble the SMD nuts and 2.0mm headers for you.

Solder the SMD nuts to the rear of the frontpanel.

Place the nut into the hole and add some solder around the edges,
then heat up the nut to melt the solder on both sides to flow the nut into place. 
A good mechanical connection is important. When in doubt, a bit of solder
can be added on the other side.

Use a hot air station or hot plate if you have one.

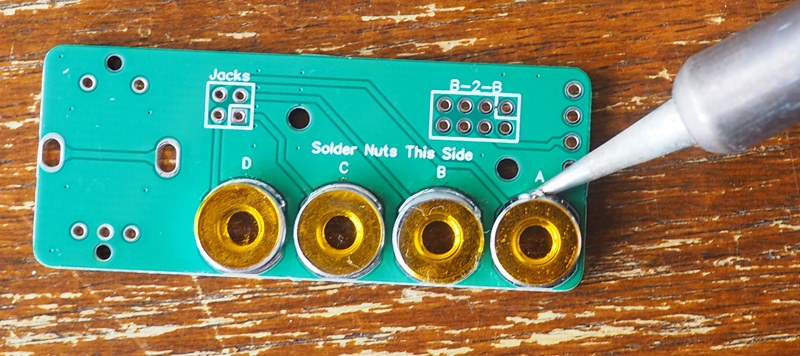
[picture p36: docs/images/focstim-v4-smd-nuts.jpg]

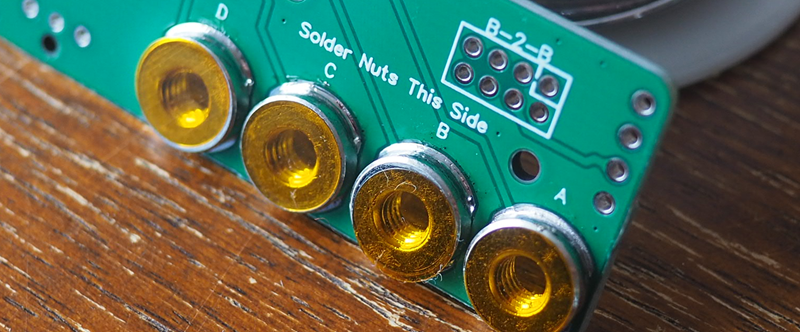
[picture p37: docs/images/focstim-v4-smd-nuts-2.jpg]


Solder the 2.0mm connectors to the same side and test fit. 

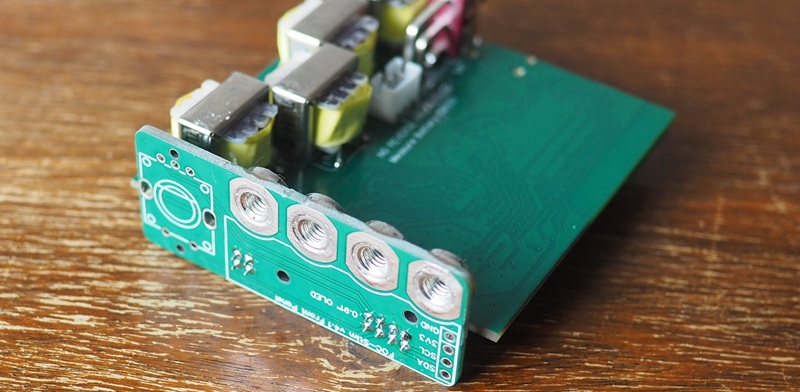
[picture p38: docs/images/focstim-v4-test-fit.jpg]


Solder the 2.54mm pins to the display.  
Place the display and frontpanel into the assembly fixture and solder the parts together.

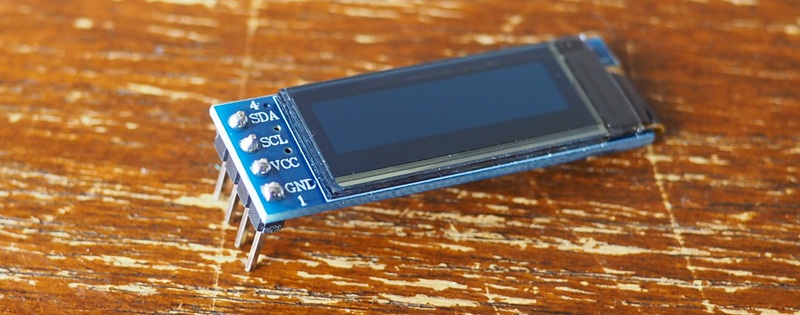
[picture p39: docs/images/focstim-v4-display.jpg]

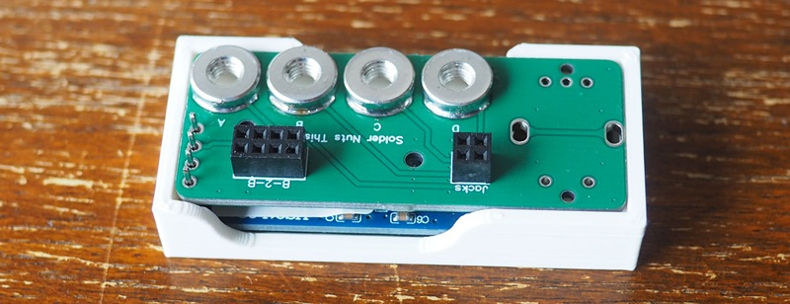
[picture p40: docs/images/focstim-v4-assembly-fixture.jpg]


Snip all pins of the display short (both sides) for clearance. Protect your eys from the flying pins!

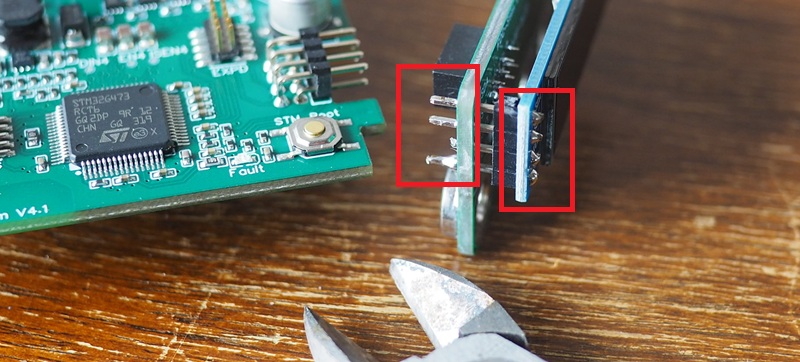
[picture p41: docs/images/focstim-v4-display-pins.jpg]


Snip off the very corner of the display for clearance in the case.

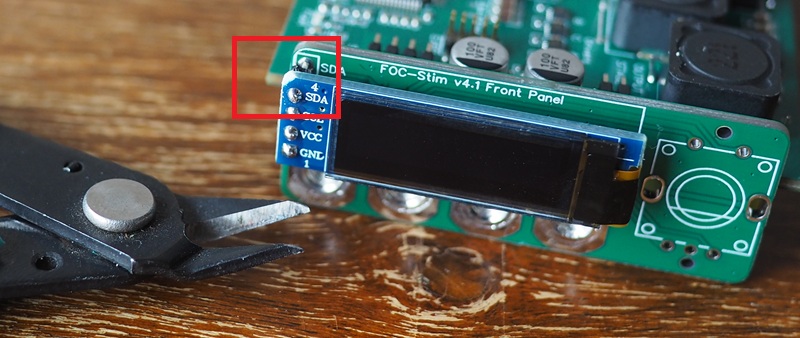
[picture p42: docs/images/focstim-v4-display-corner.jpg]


Solder the encoder and you're done.

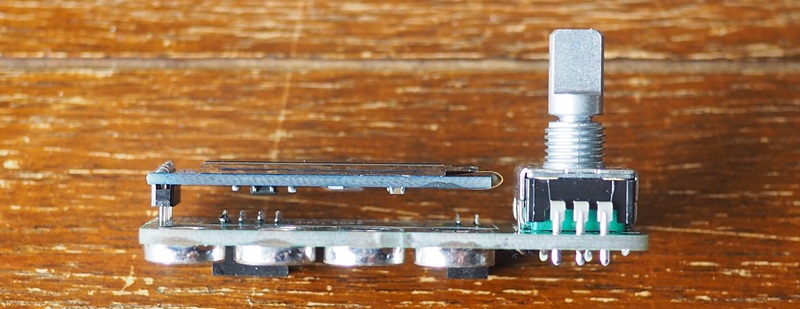
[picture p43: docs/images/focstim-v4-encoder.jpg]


# Case

[3D files and print instructions](/3d%20files/V4/readme.md)

Install the M3 heatset inserts in the battery sled.

TOOD: image showing this assembly step.

Attach the feet.

TODO: image showing this assembly step.

# Assembly

Insert the frontpanel into the case and tighten the 2mm banana jacks.
The best tool for grabbing onto the jacks is a small torx bit, just jam it into the hole.

The order is be red - blue - yellow - green.

Jacks should be a loose fit, if they are extremely tight you may delaminate the
frontpanel during tightening.

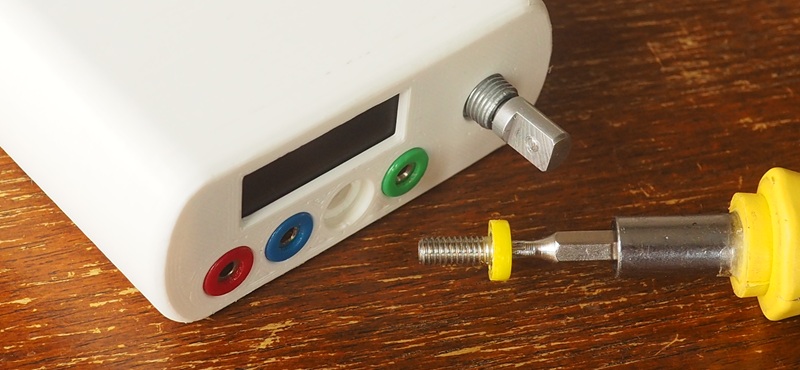
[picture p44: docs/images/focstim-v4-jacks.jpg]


Combine the mainboard, 3D-printed battery sled and rear by sliding the parts together. 

Insert the battery connector and fold the cable under the battery. 

> [!CAUTION]
> Do not pinch the battery cable against the sharp edges of the switch.

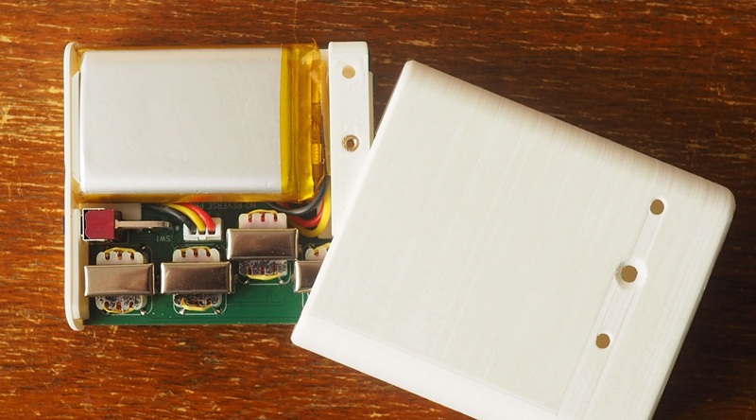
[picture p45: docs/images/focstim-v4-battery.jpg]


Slide the whole assembly into the case. Tighten the single screw on the bottom to lock the assembly.

The extra holes can be used for a belt clip.

> [!NOTE]  
> After removing/inserting the battery, USB-C power is required to power-on (just once).   

# Disassembly

Remove the screws from the bottom. Shake the case and the mainboard should slide out.  
If this does not work you can push the board out with a small allen key through the 2mm jacks
or by driving a long M4 bolt into one of the holes.

Remove the 2mm jacks with a small torx bit.

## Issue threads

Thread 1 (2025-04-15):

Restim: "Unable to open serial port: The system cannot find the path specified."

ncflagg, 2025-04-15:
Testing my FOC-stim build for the first time. Ran Restim and chose FOC-stim 3-phase. Clicking Start throws the below error:

  Unable to open serial port: The system cannot find the path specified.

Googling that error isn't showing anything useful. The B-G431B-ESC1 drivers were installed when I updated the firmware to V2J45M31. Uploading code via Visual Studio Code seemed to work.

I've tried uninstalling STM32CubeProgrammer and removing the drivers (thinking maybe it would get recognized as a standard serial port), but the Windows device name ST_Link Debug with a yellow exclamation icon.

Edit: I do see an STLink Virtual COM port (COM3), but I don't see any configuration options in Restim in order to choose a specific COM port

diglet48, 2025-04-24:
Glad you figured out a solution.

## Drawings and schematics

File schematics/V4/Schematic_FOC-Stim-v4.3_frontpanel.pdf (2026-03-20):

# Board-to-Board Interconnect Encoder

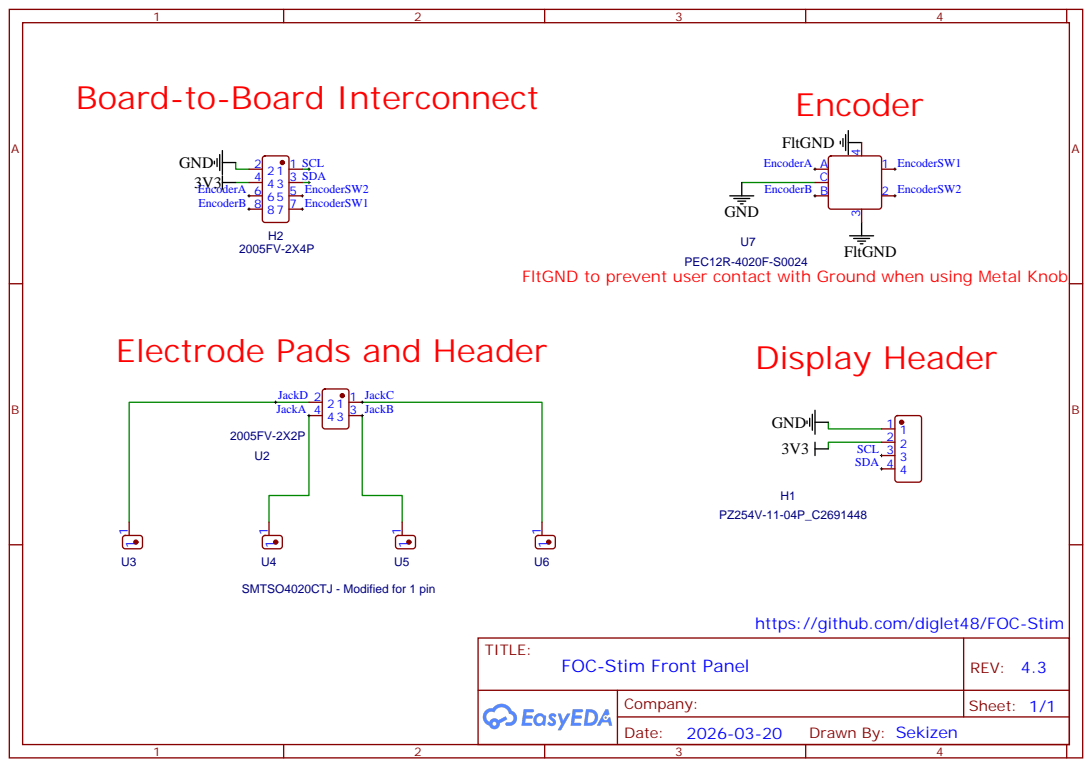
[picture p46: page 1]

FltGND to prevent user contact with Ground when using Metal Knob

https://github.com/diglet48/FOC-Stim

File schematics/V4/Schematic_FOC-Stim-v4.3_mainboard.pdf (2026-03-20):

# Battery PMIC

# USBC

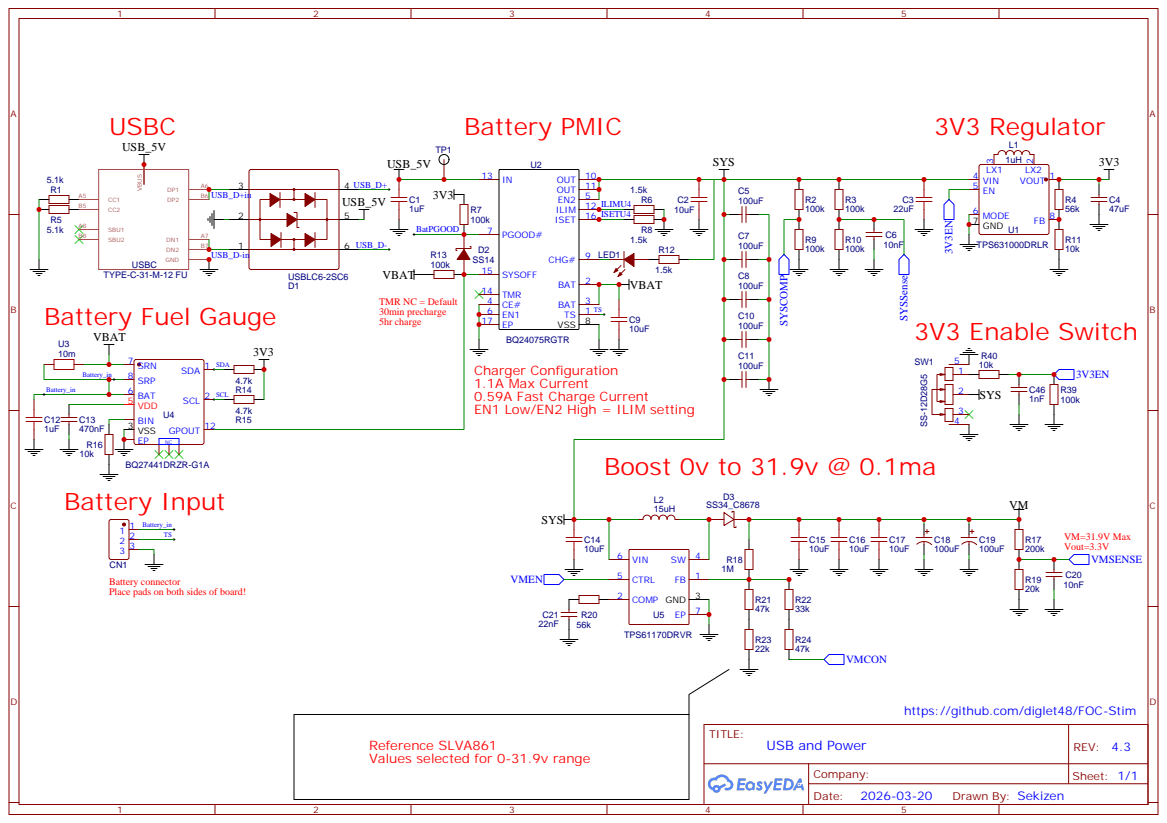
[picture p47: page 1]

BQ24075RGTR
Charger Configuration
1.1A Max Current
0.59A Fast Charge Current
EN1 Low/EN2 High = ILIM setting

https://github.com/diglet48/FOC-Stim

Reference SLVA861
Values selected for 0-31.9v range

# STM32 MCU

# ESP32 MCU

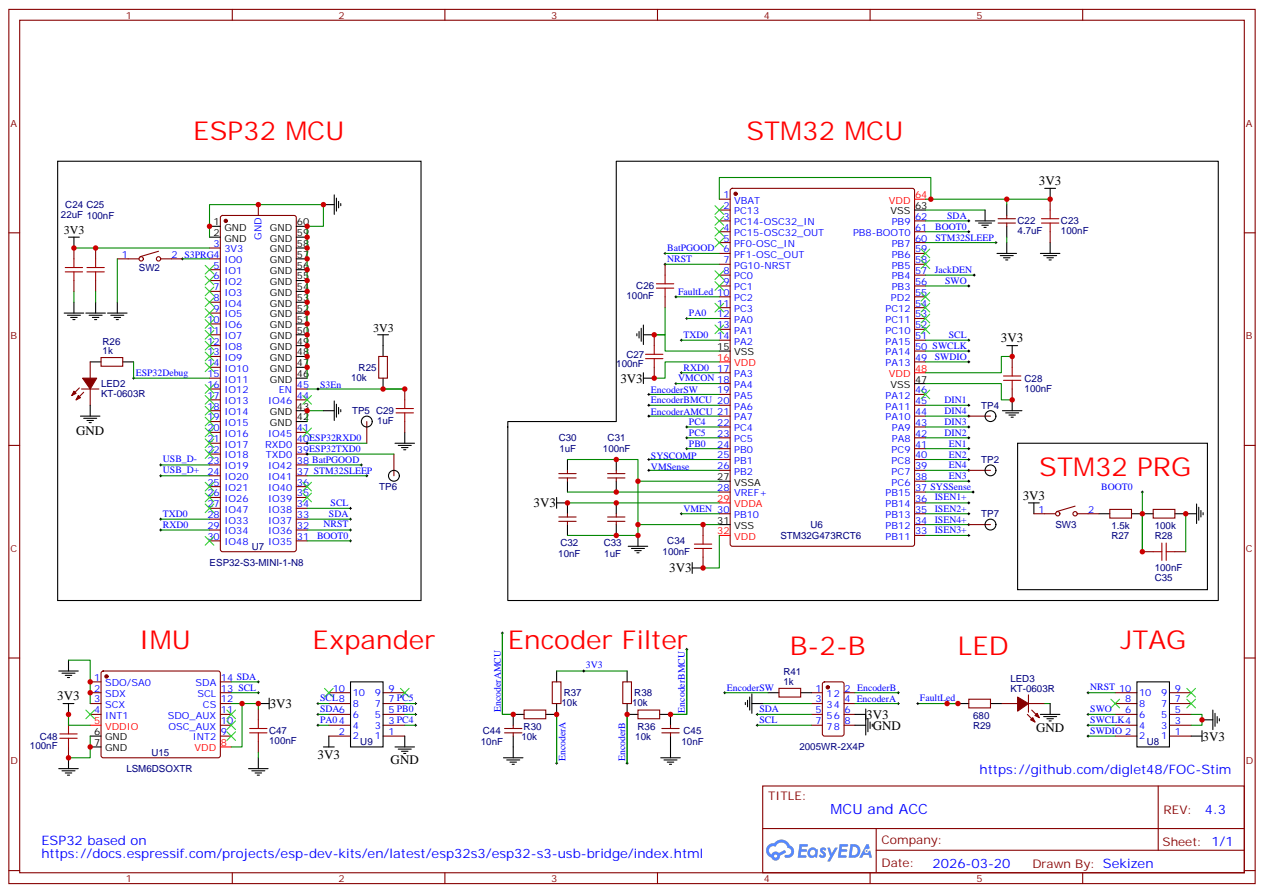
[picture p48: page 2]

https://github.com/diglet48/FOC-Stim

ESP32 based on
https://docs.espressif.com/projects/esp-dev-kits/en/latest/esp32s3/esp32-s3-usb-bridge/index.html

# Driver ICs

# Output Stage

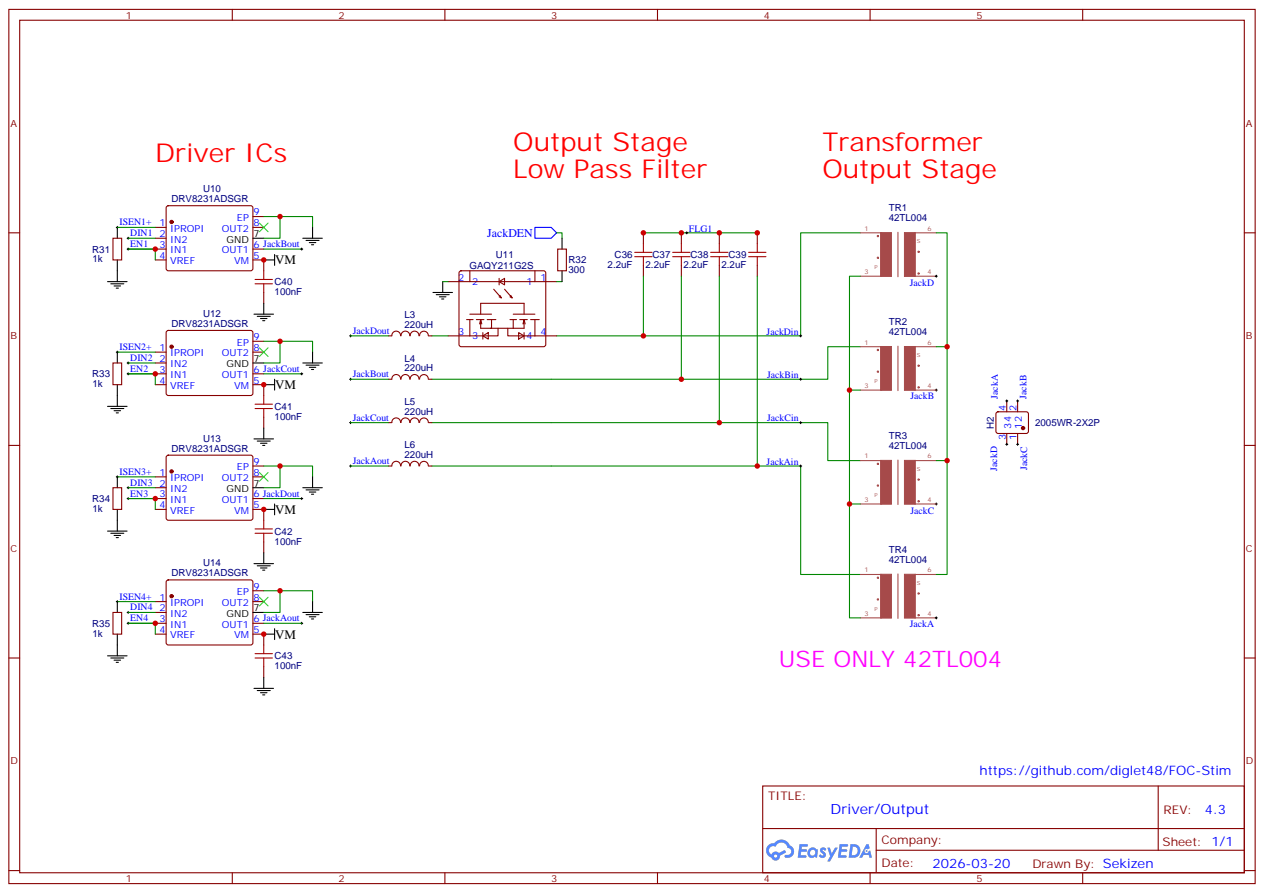
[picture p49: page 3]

https://github.com/diglet48/FOC-Stim

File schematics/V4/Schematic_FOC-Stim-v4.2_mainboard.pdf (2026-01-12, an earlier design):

# Battery PMIC

# USBC

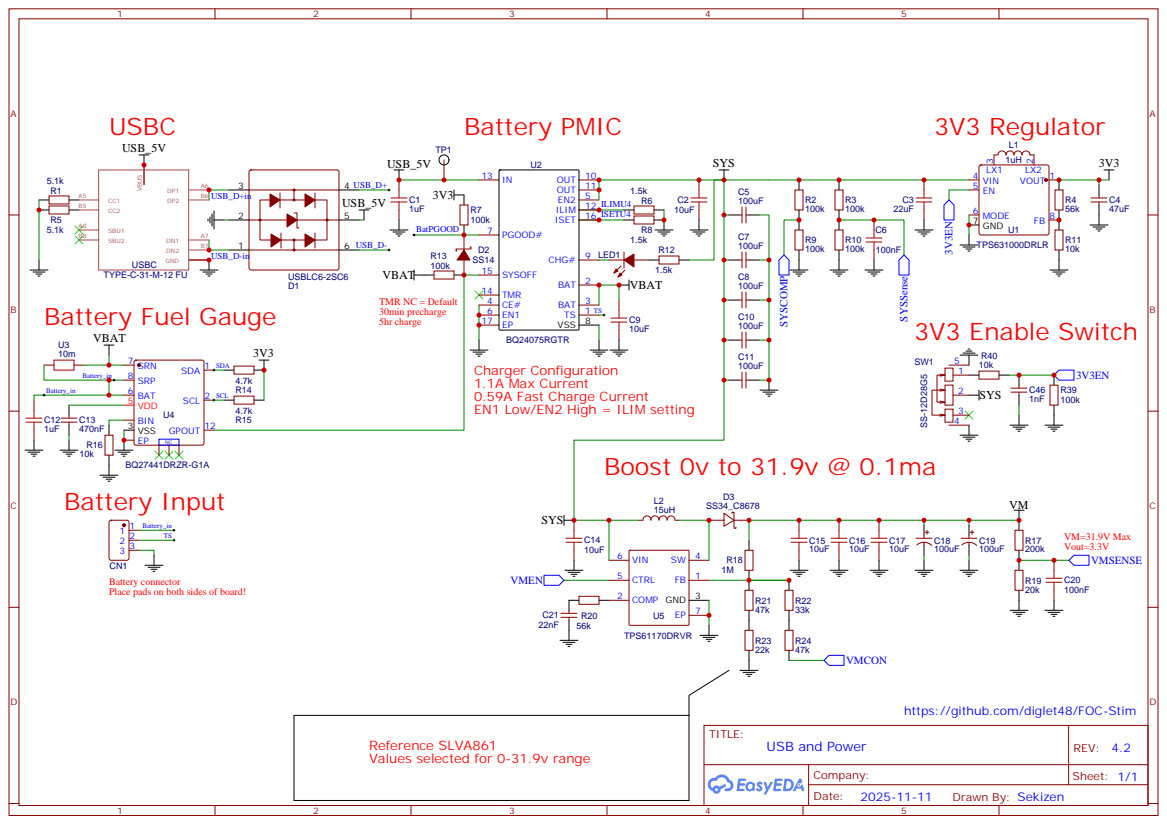
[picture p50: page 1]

BQ24075RGTR
Charger Configuration
1.1A Max Current
0.59A Fast Charge Current
EN1 Low/EN2 High = ILIM setting

https://github.com/diglet48/FOC-Stim

Reference SLVA861
Values selected for 0-31.9v range

# STM32 MCU

# ESP32 MCU

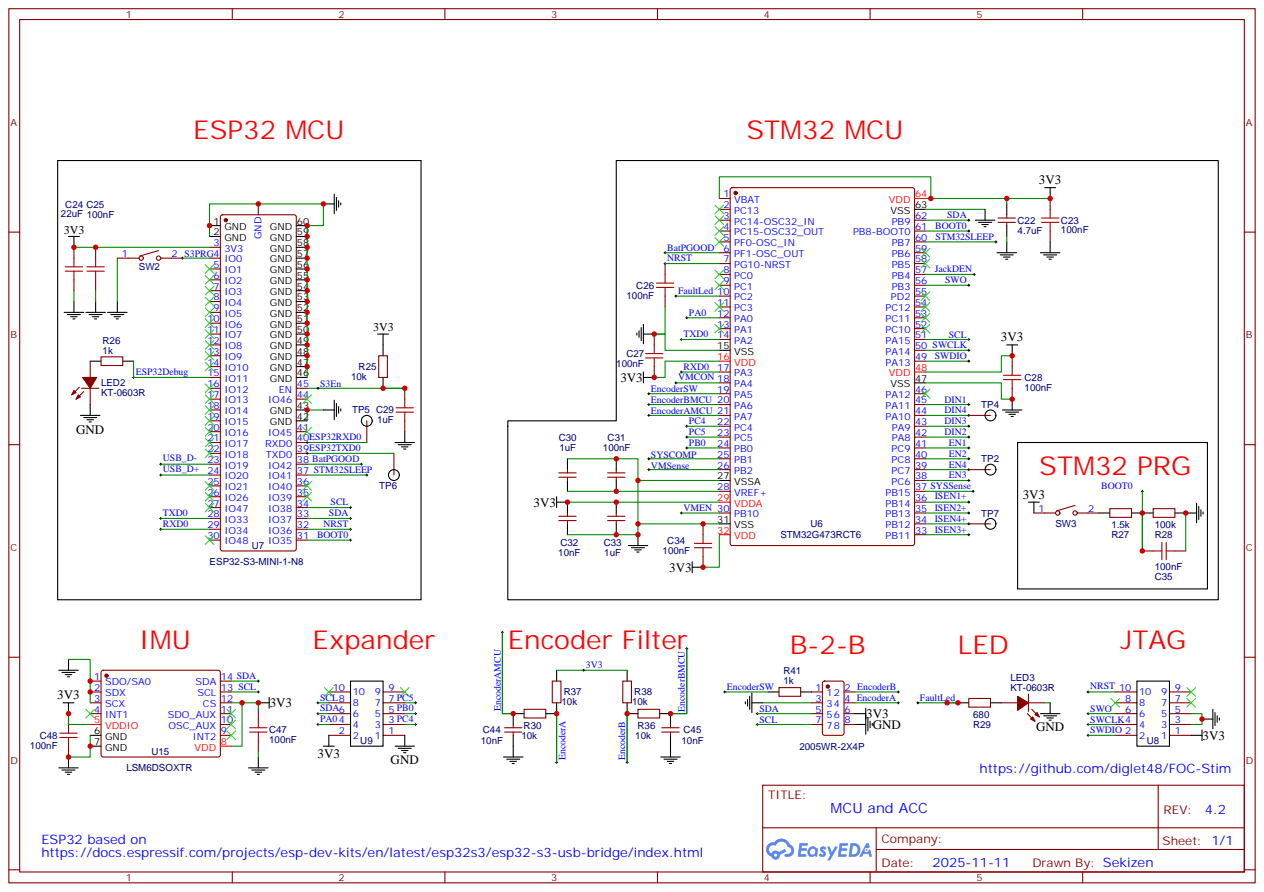
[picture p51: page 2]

https://github.com/diglet48/FOC-Stim

ESP32 based on
https://docs.espressif.com/projects/esp-dev-kits/en/latest/esp32s3/esp32-s3-usb-bridge/index.html

# Driver ICs

# Output Stage

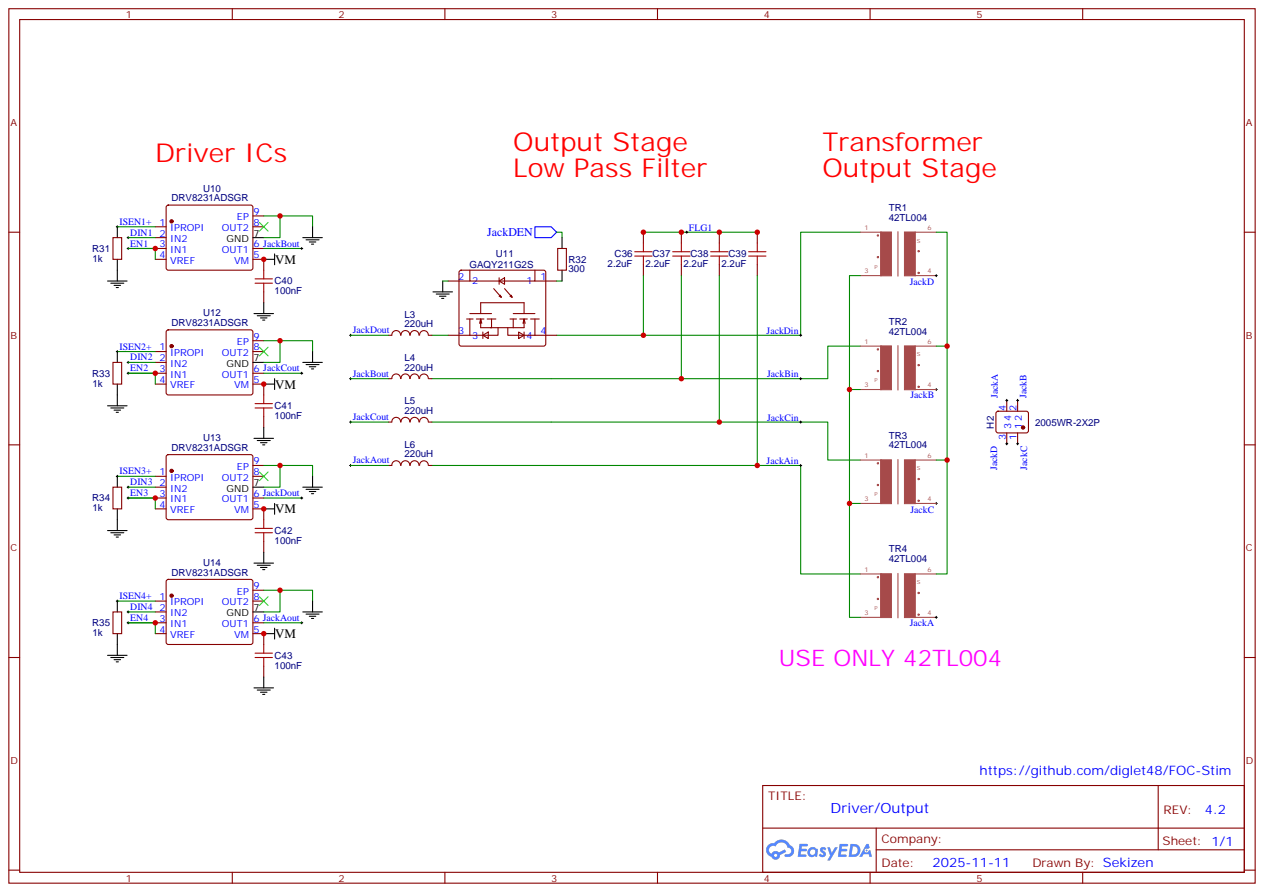
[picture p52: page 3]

https://github.com/diglet48/FOC-Stim

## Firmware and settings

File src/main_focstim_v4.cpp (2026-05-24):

#if defined(BOARD_FOCSTIM_V4)

#include <Arduino.h>

#include "foc_utils.h"
#include "utils.h"
#include "stim_clock.h"
#include "trace.h"
#include "complex.h"
#include "signals/threephase_math.h"
#include "signals/threephase_model.h"
#include "signals/fourphase_math.h"
#include "signals/fourphase_model.h"
#include "battery/power_manager.h"
#include "battery/boost_control.h"
#include <Wire.h>
#include "axis/simple_axis.h"
#include "timestamp_sync.h"
#include "sensors/as5311.h"
#include "sensors/imu.h"
#include "sensors/pressure.h"
#include "user_interface/user_interface.h"
#include "user_interface/encoder.h"
#include "user_interface/button.h"
#include "esp32.h"
#include "foc_error.h"

#include "bsp/bsp.h"
#include "bsp/bootloader.h"

#include "focstim_rpc.pb.h"
#include "protobuf_api.h"
#include "signals/transformers.h"
#include "signals/output_stage.h"

Trace trace{};
ThreephaseModel model3{};
FourphaseModel model4{};
PowerManager power_manager{};
UserInterface user_interface{};
ESP32 esp32;
IMU imu;
AS5311 as5311{};
PressureSensor pressureSensor{};
Encoder encoder{};
Button button{};
BoostControl boostControl{};


enum PlayStatus{
    NotPlaying,
    PlayingThreephase,
    PlayingFourphase
};
static PlayStatus play_status = PlayStatus::NotPlaying;


class FocstimV4ProtobufAPI : public ProtobufAPI {
public:
    FocstimV4ProtobufAPI() {};

    focstim_rpc_Errors wifi_parameters_set(focstim_rpc_RequestWifiParametersSet &params) {
        // TODO: error checks
        esp32.set_wifi_ssid(params.ssid.bytes, params.ssid.size);
        esp32.set_wifi_password(params.password.bytes, params.password.size);
        esp32.wifi_reconnect();

        return focstim_rpc_Errors_ERROR_UNKNOWN;
    }

    focstim_rpc_Errors wifi_ip_get(focstim_rpc_RequestWifiIPGet& params, uint32_t *ip_out) {
        // TOOD: error checks
        *ip_out = esp32.ip();
        return focstim_rpc_Errors_ERROR_UNKNOWN;
    }

    focstim_rpc_Errors signal_start_threephase()
    {
        if (play_status != PlayStatus::NotPlaying) {
            return focstim_rpc_Errors_ERROR_ALREADY_PLAYING;
        }
        // transmit_notification_debug_string("START 3");

        boostControl.play_started();
        BSP_WriteLedPattern(LedPattern::PlayingVeryLow);
        play_status = PlayStatus::PlayingThreephase;
        user_interface.setState(UserInterface::Playing);
        return focstim_rpc_Errors_ERROR_UNKNOWN;
    }

    focstim_rpc_Errors signal_start_fourphase_individual_electrodes()
    {
        if (play_status != PlayStatus::NotPlaying) {
            return focstim_rpc_Errors_ERROR_ALREADY_PLAYING;
        }

        // transmit_notification_debug_string("START 4");

        boostControl.play_started();
        BSP_WriteLedPattern(LedPattern::PlayingVeryLow);
        play_status = PlayStatus::PlayingFourphase;
        user_interface.setState(UserInterface::Playing);
        return focstim_rpc_Errors_ERROR_UNKNOWN;
    }

    void signal_stop()
    {
        // transmit_notification_debug_string("STOP");

        boostControl.play_stopped();
        BSP_WriteLedPattern(LedPattern::Idle);
        user_interface.setState(UserInterface::Idle);   // TOOD: force display update
        play_status = PlayStatus::NotPlaying;
        imu.stop_stream();
    }

    virtual focstim_rpc_Errors lsm6dsox_start(focstim_rpc_RequestLSM6DSOXStart& params,
        float *acc_sensitivity_out, float *gyr_sensitivity_out)
    {
        if (!imu.is_sensor_detected) {
            return focstim_rpc_Errors_ERROR_UNKNOWN_REQUEST;
        }
        imu.start_stream(params.imu_samplerate, (int)params.acc_fullscale, (int)params.gyr_fullscale);

        *acc_sensitivity_out = imu.acc_sensitivity;
        *gyr_sensitivity_out = imu.gyr_sensitivity;
        return focstim_rpc_Errors_ERROR_UNKNOWN;
    }

    virtual focstim_rpc_Errors lsm6dsox_stop() {
        imu.stop_stream();
        return focstim_rpc_Errors_ERROR_UNKNOWN;
    }

    virtual focstim_rpc_Errors lock_device_volume(bool locked) {
        encoder.setLocked(locked);
        return focstim_rpc_Errors_ERROR_UNKNOWN;
    }

    virtual void before_bootloader() {
        // hardware bug: when in bootloader mode, the driver pins are configured
        // in such a way that one driver is enabled. This causes current flow
        // that saturates the transformer and repeatedly hits the current limit
        // of the driver.
        // mitigation: drain the boost circuit caps before entering bootloader.
        BSP_SetBoostVoltage(0);         // disable boost circuit
        BSP_SetBoostEnable(false);
        BSP_SetPWM4Atomic(0, 0, 0, 0);
        BSP_OutputEnable(1, 1, 1, 1);   // enable all drivers to drain all the energy in the boost caps
        Clock k;
        while (BSP_ReadVBus() > 6) {    // drain to 6v
            k.step();
            if (k.time_seconds > 1) {
                // give up after 1 second
                break;
            }
        }
        BSP_DisableOutputs();

        user_interface.setState(UserInterface::FirmwareUpdate);
        user_interface.repaint();
        user_interface.full_update();
    }

    virtual bool capability_threephase() {return true;};
    virtual bool capability_fourphase() {return true;};
    virtual bool capability_device_volume() {return true;};
    virtual bool capability_battery() {return power_manager.is_battery_present;};
    virtual bool capability_lsm6dsox() {return imu.is_sensor_detected;};

    void transmit_notification_system_stats(float v_boost_min, float v_boost_max) {
        focstim_rpc_RpcMessage message = focstim_rpc_RpcMessage_init_zero;
        message.which_message = focstim_rpc_RpcMessage_notification_tag;
        message.message.notification.which_notification = focstim_rpc_Notification_notification_system_stats_tag;
        message.message.notification.notification.notification_system_stats.which_system = focstim_rpc_NotificationSystemStats_focstimv3_tag;
        Vec2f vsys_range = BSP_ReadVSYSRange();
        message.message.notification.notification.notification_system_stats.system.focstimv3 = {
            .temp_stm32 = BSP_ReadTemperatureSTM(),
            .v_sys_min = vsys_range.a,
            .v_ref = BSP_ReadChipAnalogVoltage(),
            .v_boost_min = v_boost_min,
            .boost_duty_cycle = BSP_BoostDutyCycle(),
            .v_sys_max = vsys_range.b,
            .v_boost_max = v_boost_max,
        };
        transmit_message(message);
    }

};

FocstimV4ProtobufAPI protobuf{};
ProtobufAPI* g_protobuf = &protobuf;

struct {
    SimpleAxis alpha{focstim_rpc_AxisType_AXIS_POSITION_ALPHA, 0, -1, 1};
    SimpleAxis beta{focstim_rpc_AxisType_AXIS_POSITION_BETA, 0, -1, 1};
    // SimpleAxis gamma{focstim_rpc_AxisType_AXIS_POSITION_GAMMA, 0, -1, 1};
    SimpleAxis waveform_amplitude_amps{focstim_rpc_AxisType_AXIS_WAVEFORM_AMPLITUDE_AMPS, 0, 0, BODY_CURRENT_MAX};
    SimpleAxis carrier_frequency{focstim_rpc_AxisType_AXIS_CARRIER_FREQUENCY_HZ, 800, 300, 2000};
    SimpleAxis pulse_frequency{focstim_rpc_AxisType_AXIS_PULSE_FREQUENCY_HZ, 50, 1, 100};
    SimpleAxis pulse_width{focstim_rpc_AxisType_AXIS_PULSE_WIDTH_IN_CYCLES, 6, 3, 20};
    SimpleAxis pulse_rise{focstim_rpc_AxisType_AXIS_PULSE_RISE_TIME_CYCLES, 5, 2, 10};
    SimpleAxis pulse_interval_random{focstim_rpc_AxisType_AXIS_PULSE_INTERVAL_RANDOM_PERCENT, 0, 0, 1};
    SimpleAxis calib_center{focstim_rpc_AxisType_AXIS_CALIBRATION_3_CENTER, 0, -10, 10};
    SimpleAxis calib_ud{focstim_rpc_AxisType_AXIS_CALIBRATION_3_UP, 0, -10, 10};
    SimpleAxis calib_lr{focstim_rpc_AxisType_AXIS_CALIBRATION_3_LEFT, 0, -10, 10};
    SimpleAxis calib_4_center{focstim_rpc_AxisType_AXIS_CALIBRATION_4_CENTER, 0, -10, 10};
    SimpleAxis calib_4a{focstim_rpc_AxisType_AXIS_CALIBRATION_4_A, 0, -10, 10};
    SimpleAxis calib_4b{focstim_rpc_AxisType_AXIS_CALIBRATION_4_B, 0, -10, 10};
    SimpleAxis calib_4c{focstim_rpc_AxisType_AXIS_CALIBRATION_4_C, 0, -10, 10};
    SimpleAxis calib_4d{focstim_rpc_AxisType_AXIS_CALIBRATION_4_D, 0, -10, 10};
    SimpleAxis calib_4_reduction_in_center{focstim_rpc_AxisType_AXIS_CALIBRATION_4_REDUCTION_IN_CENTER, .14f, 0, .2f};
    SimpleAxis e1{focstim_rpc_AxisType_AXIS_ELECTRODE_1_POWER, 0, 0, 1};
    SimpleAxis e2{focstim_rpc_AxisType_AXIS_ELECTRODE_2_POWER, 0, 0, 1};
    SimpleAxis e3{focstim_rpc_AxisType_AXIS_ELECTRODE_3_POWER, 0, 0, 1};
    SimpleAxis e4{focstim_rpc_AxisType_AXIS_ELECTRODE_4_POWER, 0, 0, 1};
} simple_axes;

void trigger_emergency_stop(FOCError error)
{
    BSP_DisableOutputs();
    BSP_SetBoostEnable(false);
    BSP_WriteLedPattern(LedPattern::Error);

    switch (error) {
        case OUTPUT_OVER_CURRENT:
        case MODEL_TIMING_ERROR:
        trace.print_mainloop_trace();
        if (play_status == PlayStatus::PlayingThreephase) {
            model3.debug_stats_teleplot();
        }
        if (play_status == PlayStatus::PlayingFourphase) {
            model4.debug_stats_teleplot();
        }
        break;
        case BOOST_VOLTAGE_NOT_RISING:
        case BOOST_UNDER_VOLTAGE:
        case BOOST_OVER_VOLTAGE:
        case BOARD_OVER_TEMPERATURE:
        case I2C_BUS_HANG:
        break;
    }

    play_status = PlayStatus::NotPlaying;
    user_interface.setState(UserInterface::Error);
    user_interface.repaint();
    user_interface.full_update();
}
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
void loop()
{
    static Clock total_pulse_length_timer;
    static float pulse_total_duration = 0;
    static Clock actual_pulse_frequency_clock;
    static Clock rms_current_clock;
    static Clock status_print_clock;
    static Clock vbus_print_clock;
    static Clock vbus_high_clock;
    static uint32_t pulse_counter = 0;
    static float actual_pulse_frequency = 0;
    static Clock print_system_stats_clock;
    static float v_drive_max = 0;
    static float v_boost_min = 99;
    static float v_boost_max = 0;
    static Clock ip_refresh_clock;
    static Clock boost_not_ready_clock;
    static bool boost_is_ready = false;

    static Clock device_volume_nospam;
    static float device_volume_last_value = 0;

    // do comms
    protobuf.process_incoming_messages();

    // safety: temperature
    float temperature = BSP_ReadTemperatureSTM();
    if (temperature >= MAXIMUM_TEMPERATURE) {
        trigger_emergency_stop(FOCError::BOARD_OVER_TEMPERATURE);
        while (1)
        {
            BSP_PrintDebugMsg(
                "temperature limit exceeded %.2f. Current temperature=%.2f. Restart device to proceed.",
                temperature, BSP_ReadTemperatureSTM());
            delay(5000);
        }
    }

    float vbus = BSP_ReadVBus();
    v_boost_min = min(v_boost_min, vbus);
    v_boost_max = max(v_boost_max, vbus);
    // safety: boost overvoltage
    if (vbus >= BOOST_OVERVOLTAGE_THRESHOLD) {
        trigger_emergency_stop(FOCError::BOOST_OVER_VOLTAGE);
        while (1)
        {
            BSP_PrintDebugMsg(
                "boost overvoltage detected %.2f. Current boost=%.2f. Restart device to proceed.",
                vbus, BSP_ReadVBus());
            delay(5000);
        }
    }

    // check for hung I2C bus
    // note: if the I2C bus hangs, we can't update the display anymore...
    if (digitalRead(PA15) == 0 && digitalRead(PB9) == 0) {
        trigger_emergency_stop(FOCError::I2C_BUS_HANG);
        while (1) {
            BSP_PrintDebugMsg("I2C bus hang");
            delay(5000);
        }
    }

    // encoder stuff
    encoder.update();
    device_volume_nospam.step();
    bool do_transmit_device_volume = false;
    do_transmit_device_volume |= (device_volume_nospam.time_seconds > 1);
    do_transmit_device_volume |= (device_volume_nospam.time_seconds > 0.1f
        && (encoder.volume() != device_volume_last_value));
    if (do_transmit_device_volume) {
        device_volume_nospam.reset();
        device_volume_last_value = encoder.volume();
        protobuf.transmit_notification_device_volume(encoder.volume(), encoder.isLocked());
    }

    // process button events
    switch (button.getEvent()) {
        case ButtonEvent::Press:
            protobuf.transmit_notification_button_press(true, millis());
            break;
        case ButtonEvent::Release:
            protobuf.transmit_notification_button_press(false, millis());
        break;
        default:
        break;
    };

    // process encoder quick-turns
    if (encoder.isLocked()) {
        if (encoder.isQuickTurned()) {
            encoder.setLocked(false);
            encoder.resetVolume();
            protobuf.transmit_notification_device_volume(encoder.volume(), encoder.isLocked());
        }
    }
    user_interface.setLockState(encoder.isLocked());
    user_interface.setUnlockProgress(encoder.unlockProgress());
    user_interface.setPowerLevel(encoder.volume());

    // every few seconds, print system stats
    print_system_stats_clock.step();
    if (print_system_stats_clock.time_seconds > .5) {
        print_system_stats_clock.reset();
        protobuf.transmit_notification_system_stats(v_boost_min, v_boost_max);
        v_boost_min = 99;
        v_boost_max = 0;

        if (power_manager.is_battery_present) {
            protobuf.transmit_notification_battery(
                power_manager.cached_voltage,
                power_manager.cached_soc(),
                power_manager.cached_power,
                power_manager.cached_temperature,
                !BSP_ReadPGood());
            user_interface.setBatterySoc(power_manager.cached_soc());
        }
    }

    // if not playing, regularly query the IP address from the esp32
    ip_refresh_clock.step();
    if (ip_refresh_clock.time_seconds > 0.4f && play_status == PlayStatus::NotPlaying) {
        user_interface.setIP(esp32.ip());
        ip_refresh_clock.reset();
    }

    as5311.update();
    imu.update();
    pressureSensor.update();
    power_manager.update();

    // update small slice of the display
    user_interface.repaint();
    user_interface.partial_update();

    // start/stop
    if (play_status == PlayStatus::NotPlaying) {
        boost_not_ready_clock.reset();
        BSP_WriteLedPattern(LedPattern::Idle);
        return;
    }

    // keepalive timer. Stop playing if no messages have been received for some time.
    if (protobuf.time_since_last_axis_command.time_seconds > 4) {
        BSP_PrintDebugMsg("Comms lost? Stopping.");
        play_status = PlayStatus::NotPlaying;
        BSP_WriteLedPattern(LedPattern::Idle);
        user_interface.setState(UserInterface::Idle);
        boostControl.play_stopped();
        imu.stop_stream();
        return;
    }

    // stall out idle portion of the pulse
    total_pulse_length_timer.step();
    if (total_pulse_length_timer.time_seconds <= pulse_total_duration) {
        return;
    }

    // delay pulse until the boost capacitors are filled up, reducing the pulse frequency if neccesairy
    if (! boostControl.boost_is_ready()) {
        if (boost_is_ready) {
            boost_is_ready = false;
            boost_not_ready_clock.reset();
        }

        // if it takes excessively long to charge the boost caps, trigger undervoltage error.
        boost_not_ready_clock.step();
        if (boost_not_ready_clock.time_seconds > 0.1f) {
            trigger_emergency_stop(FOCError::BOOST_UNDER_VOLTAGE);
            trace.print_mainloop_trace();
            while (1)
            {
                BSP_PrintDebugMsg(
                    "boost undervoltage detected %.2f. Current boost=%.2f. Restart device to proceed.",
                    vbus, BSP_ReadVBus());
                delay(5000);
            }
        }
        return;
    }
    boost_is_ready = true;

    // ready to generate next pulse!
    MainLoopTraceLine *traceline = trace.next_main_loop_line();
    total_pulse_length_timer.reset();
    traceline->t_start = total_pulse_length_timer.last_update_time;

    // calculate stats
    pulse_counter++;
    actual_pulse_frequency_clock.step();
    actual_pulse_frequency = lerp(.05f, actual_pulse_frequency, 1e6f / actual_pulse_frequency_clock.dt_micros);

    // get all the pulse parameters
    uint32_t now_ms = millis();
    float pulse_alpha = simple_axes.alpha.get(now_ms);
    float pulse_beta = simple_axes.beta.get(now_ms);
    // float pulse_gamma = simple_axes.gamma.get(now_ms);
    float body_current_amps = simple_axes.waveform_amplitude_amps.get(now_ms);

    float pulse_carrier_frequency = simple_axes.carrier_frequency.get(now_ms);
    float pulse_frequency = simple_axes.pulse_frequency.get(now_ms);
    float pulse_width = simple_axes.pulse_width.get(now_ms);
    float pulse_rise = simple_axes.pulse_rise.get(now_ms);
    float pulse_interval_random = simple_axes.pulse_interval_random.get(now_ms);

    float calibration_center = simple_axes.calib_center.get(now_ms);
    float calibration_lr = simple_axes.calib_lr.get(now_ms);
    float calibration_ud = simple_axes.calib_ud.get(now_ms);

    float calibration_4a = simple_axes.calib_4a.get(now_ms);
    float calibration_4b = simple_axes.calib_4b.get(now_ms);
    float calibration_4c = simple_axes.calib_4c.get(now_ms);
    float calibration_4d = simple_axes.calib_4d.get(now_ms);
    float calibration_4_reduction_in_center = simple_axes.calib_4_reduction_in_center.get(now_ms);

    float electrode_a = simple_axes.e1.get(now_ms);
    float electrode_b = simple_axes.e2.get(now_ms);
    float electrode_c = simple_axes.e3.get(now_ms);
    float electrode_d = simple_axes.e4.get(now_ms);

    // clip pulse width to 35ms to avoid uart overflows from super long pulses.
    pulse_width = std::min<float>(pulse_width, 0.035f * pulse_carrier_frequency);

    float pulse_active_duration = pulse_width / pulse_carrier_frequency;
    float pulse_pause_duration = max(0.f, 1 / pulse_frequency - pulse_active_duration);
    pulse_pause_duration *= float_rand(1 - pulse_interval_random, 1 + pulse_interval_random);
    pulse_total_duration = pulse_active_duration + pulse_pause_duration;
    traceline->dt_next = pulse_total_duration * 1e6f;

    // mix in encoder
    body_current_amps *= encoder.volume();
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

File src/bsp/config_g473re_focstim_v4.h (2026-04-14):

#if defined(BOARD_FOCSTIM_V4)
#ifndef FOCSTIM_CONFIG_G473RE_FOCSTIM_V4_H
#define FOCSTIM_CONFIG_G473RE_FOCSTIM_V4_H

#include "../signals/transformers.h"
#include "../signals/output_stage.h"

// transformer and output stage specs
static constexpr OutputStage OUTPUT_STAGE = {
    .resistance = 0.68f,    // driver Rdson (0.28) + inductor DC resistance (0.3) + traces (0.1 ohm)
    .inductance = 220e-6f,  // µH
    .capacitance = 2.2e-6f, // µF
#ifdef TRANSFORMER_42TL004
    .transformer = XICON_42TL004,
#elifdef TRANSFORMER_42TL001
    .transformer = XICON_42TL001,
#else
#error no transformer type declared
#endif
};

// current limits
#define BODY_CURRENT_MAX  0.20f  // in amps
#define ESTOP_CURRENT_LIMIT_MARGIN 0.12f    // accounts for measurement noise, driving current

// board temperature limits
#define MAXIMUM_TEMPERATURE 60.f    // degrees celsius.

// boost voltage control
#define STIM_DYNAMIC_VOLTAGE
#define BOOST_MINIMUM_VOLTAGE       10.f            // boost voltage setpoint (min)
#define BOOST_MAXIMUM_VOLTAGE       29.5f           // boost voltage setpoint (max)
#define BOOST_OVERVOLTAGE_THRESHOLD 31.f            // e-stop when exceeded

// pwm
#define STIM_PWM_FREQ 50000 // switching frequency is twice this frequency
#define STIM_PWM_MINIMUM_OFF_TIME 3e-6f // limited by pwm-rejection of current sense. Experimentally determined to be 2.6us.
#define STIM_PWM_MAX_DUTY_CYCLE float(1 - STIM_PWM_MINIMUM_OFF_TIME * STIM_PWM_FREQ)
#define STIM_PWM_MAX_VDRIVE (STIM_PWM_MAX_DUTY_CYCLE * STIM_BOOST_VOLTAGE_LOW_THRESHOLD)

// deadtime compensation
#define DEADTIME_COMPENSATION_ENABLE
#define DEADTIME_COMPENSATION_MAGIC_VALUE  185e-9f   // experimentally determined. Close to driver deadtime (200ns).
#define DEADTIME_COMPENSATION_PERCENTAGE (DEADTIME_COMPENSATION_MAGIC_VALUE * STIM_PWM_FREQ)
#define DEADTIME_COMPENSATION_CURRENT_THRESHOLD .025f // experimentally determined (at 22v)

// initial conditions and limits for the model
#define MODEL_IMPEDANCE_INIT {5.5f, 1.3}    // 110ohm resistors with 42TL004 @ 1000hz
#define MODEL_RESISTANCE_MIN 1.4f
#define MODEL_RESISTANCE_MAX 80.f
#define MODEL_PHASE_ANGLE_MIN -1.5f
#define MODEL_PHASE_ANGLE_MAX 1.5f

// transformer saturation
#define MODEL_FIXED_RESISTANCE      1.7f        // traces (0.1) + driver Rdson (0.3) + low pass filter (0.3) + transformer low-side resistance (1.0)
#define MODEL_MAXIMUM_VOLT_SECONDS  1100e-6f    // Xicon 42TL004 and 001

// I2C clocks
#define I2C_CLOCK_NORMAL        400'000ULL
#define I2C_CLOCK_DISPLAY       1'000'000ULL
#define I2C_CLOCK_LSM6DSOX      1'000'000ULL
#define I2C_CLOCK_MICROPRESSURE 400'000ULL
#define I2C_CLOCK_BQ27411       400'000ULL
#define I2C_CLOCK_ESP32         400'000ULL

// enable for nicer looking waveforms on the scope. Not safe for humans!
// #define THREEPHASE_PULSE_DEFEAT_RANDOMIZATION

#define CURRENT_SENSE_SCALE_HALF
#define BSP_ENABLE_FOURPHASE
#define BATTERY_ENABLE

#endif
#endif

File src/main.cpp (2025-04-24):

#include <Arduino.h>

#include "foc_utils.h"
#include "tcode.h"
#include "utils.h"
#include "stim_clock.h"
#include "trace.h"
#include "complex.h"
#include "signals/threephase_math.h"
#include "signals/threephase_model.h"
#include "signals/fourphase_math.h"
#include "signals/fourphase_model.h"

#include "bsp/bsp.h"


Trace trace{};

#if defined(BSP_ENABLE_THREEPHASE)
ThreephaseModel model{};
#elif defined(BSP_ENABLE_FOURPHASE)
FourphaseModel model{};
#endif


static bool status_booted = false;
static bool status_vbus = false;
static bool status_estop = false;
static bool status_playing = false;

static Clock keepalive_clock{};


void print_status() {
    uint32_t status =
        (status_booted << 0)
        | (status_vbus << 1)
        | (status_estop << 2)
        | (status_playing << 3);
    Serial.printf("status: %lu\r\n", status);
}


void tcode_D0() {
    Serial.println();
    Serial.printf("version: FOC-Stim 0.5\r\n");
    print_status();
}

void tcode_DSTART() {
    if (status_vbus && !status_playing) {
        Serial.printf("Pulse generation started\r\n");
        status_playing = true;
    }
}

void tcode_DSTOP() {
    if (status_vbus && status_playing) {
        Serial.printf("Pulse generation stopped\r\n");
        status_playing = false;
    }
}

void tcode_DPING() {
    keepalive_clock.reset();
}

struct
{
    TCodeAxis alpha{"L0", 0, -1, 1};
    TCodeAxis beta{"L1", 0, -1, 1};
    TCodeAxis gamma{"L2", 0, -1, 1};
    TCodeAxis volume{"V0", 0, 0, TCODE_MAX_CURRENT};
    TCodeAxis carrier_frequency{"A0", 800, 500, 2000};
    TCodeAxis pulse_frequency{"A1", 50, 1, 100};
    TCodeAxis pulse_width{"A2", 6, 3, 20};
    TCodeAxis pulse_rise{"A3", 5, 2, 10};
    TCodeAxis pulse_interval_random{"A4", 0, 0, 1};
    TCodeAxis calib_center{"C0", 0, -10, 10};
    TCodeAxis calib_ud{"C1", 0, -10, 10};
    TCodeAxis calib_lr{"C2", 0, -10, 10};
    TCodeAxis calib_4a{"C3", 0, -10, 10};
    TCodeAxis calib_4b{"C4", 0, -10, 10};
    TCodeAxis calib_4c{"C5", 0, -10, 10};
    TCodeAxis calib_4d{"C6", 0, -10, 10};
} axes;
struct {
    TCodeDeviceCommand d0{"0", &tcode_D0};
    TCodeDeviceCommand d_start{"START", &tcode_DSTART};
    TCodeDeviceCommand d_stop{"STOP", &tcode_DSTOP};
    TCodeDeviceCommand d_ping{"PING", &tcode_DPING};
} tcode_device_commands;
TCode tcode(reinterpret_cast<TCodeAxis *>(&axes), sizeof(axes) / sizeof(TCodeAxis),
            reinterpret_cast<TCodeDeviceCommand *>(&tcode_device_commands), sizeof(tcode_device_commands) / sizeof(TCodeDeviceCommand));

void estop_triggered()
{
    trace.print_mainloop_trace();
    model.debug_stats_teleplot();
}

void setup()
{
    Serial.begin(115200);
    delay(100);
    Serial.println("BSP init");
    BSP_Init();

    // print status to let the computer know we have rebooted.
    print_status();
    BSP_WriteStatusLED(1);

    model.init(&estop_triggered);

    status_booted = true;
    float vbus = BSP_ReadVBus();
    if (vbus > STIM_PSU_VOLTAGE_MIN) {
        status_vbus = true;
    }
    print_status();


#if defined(BSP_ENABLE_THREEPHASE)
    BSP_OutputEnable(true, true, true);
#elif defined(BSP_ENABLE_FOURPHASE)
    BSP_OutputEnable(true, true, true, true);
    BSP_SetBoostVoltage(16);
    BSP_SetBoostMinimumInputVoltage(3.8f + 0.2f);
    // BSP_SetBoostMinimumInputVoltage(3.0f);
    BSP_SetBoostEnable(true);
#endif
}

void loop()
{
    static Clock total_pulse_length_timer;
    static float pulse_total_duration = 0;
    static Clock actual_pulse_frequency_clock;
    static Clock rms_current_clock;
    static Clock status_print_clock;
    static Clock vbus_print_clock;
    static Clock vbus_high_clock;
    static uint32_t pulse_counter = 0;
    static float actual_pulse_frequency = 0;
    static bool led_status = true;

    // do comms
    bool dirty = tcode.update_from_serial();

    // safety checks
    float temperature = BSP_ReadTemperatureOnboardNTC();
    if (temperature >= MAXIMUM_TEMPERATURE) {
        BSP_DisableOutputs();
        while (1)
        {
            Serial.printf("temperature limit exceeded %.2f. Current temperature=%.2f. Restart device to proceed\r\n",
                          temperature, BSP_ReadTemperatureOnboardNTC());
            delay(5000);
        }
    }

    float vbus = BSP_ReadVBus();
    if (vbus >= STIM_PSU_VOLTAGE_MAX) {
        BSP_DisableOutputs();
        while (1)
        {
            Serial.printf("V_BUS overvoltage detected %.2f. Current V_BUS=%.2f. Restart device to proceed\r\n",
                          vbus, BSP_ReadVBus());
            delay(5000);
        }
    }

    // check vbus, stop playing if vbus is too low.
    if (vbus < STIM_PSU_VOLTAGE_MIN) {
        vbus_high_clock.reset();

        // vbus changed high->low.
        if (status_vbus) {
            status_vbus = false;
            status_playing = false;
            Serial.printf("V_BUS under-voltage detected (V_BUS = %.2f). Stopping pulse generation.\r\n", vbus);
            print_status();
            vbus_print_clock.reset();
        }

        // print something if vbus has been low for a while to alert user they should flip power switch on the device.
        vbus_print_clock.step();
        if (vbus_print_clock.time_seconds > 4) {
            vbus_print_clock.reset();
            Serial.printf("V_BUS too low: %.2f\r\n", vbus);
        }
    } else {
        // if vbus is high and stable
        if (!status_vbus && vbus_high_clock.time_seconds > 0.2f) {
            Serial.printf("V_BUS online. V_BUS: %.2f\r\n", vbus);
            status_vbus = true;
            status_playing = false;
            print_status();
        }
        vbus_high_clock.step();
    }

    // keepalive timer. Stop playing if no messages have been received for some time.
    if (dirty) {
        keepalive_clock.reset();

        // toggle the LED every time serial comms is received.
        led_status = !led_status;
        BSP_WriteStatusLED(led_status);
    }
    keepalive_clock.step();
    if (keepalive_clock.time_seconds > 2 && status_playing) {
        Serial.println("Connection lost? Stopping pulse generation.");
        status_playing = false;
        print_status();
    }

    // correct for drift in the current sense circuit
    BSP_AdjustCurrentSenseOffsets();

    // DSTART / DSTOP
    if (! status_playing) {
        delay(10);
        return;
    }

    // stall out idle portion of the pulse
    total_pulse_length_timer.step();
    if (total_pulse_length_timer.time_seconds <= pulse_total_duration) {
        return;
    }

    // ready to generate next pulse!
    MainLoopTraceLine *traceline = trace.next_main_loop_line();
    total_pulse_length_timer.reset();
    traceline->t_start = total_pulse_length_timer.last_update_time;

    // calculate stats
    pulse_counter++;
    actual_pulse_frequency_clock.step();
    actual_pulse_frequency = lerp(.05f, actual_pulse_frequency, 1e6f / actual_pulse_frequency_clock.dt_micros);
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

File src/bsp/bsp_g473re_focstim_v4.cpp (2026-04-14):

#if defined(BOARD_FOCSTIM_V4)

#include "bsp.h"
#include "utils.h"
#include "foc_utils.h"
#include "protobuf_api.h"

#include <stm32g4xx_ll_dac.h>
#include <stm32g4xx_ll_comp.h>
#include <stm32g4xx_ll_exti.h>
#include <algorithm>


#define ADC_VOLTAGE 2.9f
#define ADC_SCALE   4095
#define DAC_MAX_VALUE 4095

#define LED_TIMER_FREQ_Hz       1'000'000UL
#define LED_TIMER_PWM_FREQ_Hz   1000UL
#define LED_TIMER_PEAK          (LED_TIMER_FREQ_Hz / LED_TIMER_PWM_FREQ_Hz)
#define RED_LED_BRIGHTNESS      1.0f

#define DRIVER_RISEN 1000
#define DRIVER_KISEN 1500 // µa / A
#define DRIVER_SENSE_CURENT_TO_COIL_CURRENT (1e6f / DRIVER_KISEN)


#define ADC_SAMPLETIME_CURRENT_SENSE    ADC_SAMPLETIME_12CYCLES_5   // [ 12.5 + 12.5] clocks = 0.58µs
#define ADC_SAMPLETIME_VREFINT          ADC_SAMPLETIME_247CYCLES_5  // [247.5 + 12.5] clocks = 6.11µs   (datasheet: min 4µs)
#define ADC_SAMPLETIME_V_TS             ADC_SAMPLETIME_247CYCLES_5  // [247.5 + 12.5] clocks = 6.11µs   (datasheet: min 5µs)
#define ADC_SAMPLETIME_VBAT             ADC_SAMPLETIME_640CYCLES_5  // [640.5 + 12.5] clocks = 15.4µs   (datasheet: min 12µs)
#define ADC_SAMPLETIME_VM               ADC_SAMPLETIME_640CYCLES_5  // [640.5 + 12.5] clocks = 15.4µs
#define ADC_SAMPLETIME_VSYS             ADC_SAMPLETIME_640CYCLES_5  // [640.5 + 12.5] clocks = 15.4µs

// experimentally determined to be right in the middle of the triangular current waveform.
// Not sure why this isn't equal to driver propagation delay minus half the sampletime.
#define ADC_CURRENT_SENSE_DELAY         290e-9f     // seconds
#define ADC_TRIGGER_FREQ                10000
#define ADC_TRIGGER_DELAY               (ADC_CURRENT_SENSE_DELAY + 1e-6f)

// Drivers EN1 (enable) pins. Output
#define DRIVER_ENABLE_GPIO_PORT GPIOC
#define DRIVER_A_ENABLE_PIN LL_GPIO_PIN_7  // PC7
#define DRIVER_B_ENABLE_PIN LL_GPIO_PIN_9  // PC9
#define DRIVER_C_ENABLE_PIN LL_GPIO_PIN_8  // PC8
#define DRIVER_D_ENABLE_PIN LL_GPIO_PIN_6  // PC6

// Drivers EN2 (direction) pins. Output via TIM1
#define DRIVER_DIN_GPIO_PORT GPIOA
#define DRIVER_A_DIN_PIN LL_GPIO_PIN_10   // PA10 DIN4 AF6  tim1_ch3
#define DRIVER_B_DIN_PIN LL_GPIO_PIN_11   // PA11 DIN1 AF11 tim1_ch4
#define DRIVER_C_DIN_PIN LL_GPIO_PIN_8    // PA8  DIN2 AF6  tim1_ch1
#define DRIVER_D_DIN_PIN LL_GPIO_PIN_9    // PA9  DIN3 AF6  tim1_ch2

// Driver IPROPI current sense pins. Analog input (opamp)
#define SEN_GPIO_PORT GPIOB
#define SEN_A_PIN LL_GPIO_PIN_12    // PB12 opamp6   ADC_CHANNEL_VOPAMP6 on ADC4
#define SEN_B_PIN LL_GPIO_PIN_14    // PB14 opamp2   ADC_CHANNEL_VOPAMP2 on ADC2
#define SEN_C_PIN LL_GPIO_PIN_13    // PB13 opamp3   ADC_CHANNEL_VOPAMP3_ADC3 (also available on ADC2)
#define SEN_D_PIN LL_GPIO_PIN_11    // PB11 opamp4   ADC_CHANNEL_VOPAMP4 on ADC5

// triac for phase 'D' enable. Output
#define OUT_D_EN_GPIO_PORT GPIOB
#define OUT_D_EN_PIN LL_GPIO_PIN_4   // PB4

// boost enable. Output open-drain with pullup enabled
#define BOOST_EN_GPIO_PORT GPIOB
#define BOOST_EN_PIN LL_GPIO_PIN_10 // PB10

// boost control. DAC1_OUT1
#define BOOST_DAC_GPIO_PORT GPIOA
#define BOOST_DAC_PIN LL_GPIO_PIN_4 // PA4

// VM sense, ADC2_IN12
#define VM_SENSE_GPIO_PORT GPIOB
#define VM_SENSE_PIN LL_GPIO_PIN_2  // PB2
#define ADC2_CHANNEL_VM_SENSE       ADC_CHANNEL_12

// VSYS sense, ADC2_IN15 and ADC4_IN5
#define VSYS_SENSE_GPIO_PORT GPIOB
#define VSYS_SENSE_PIN LL_GPIO_PIN_15 // PB15
#define ADC4_CHANNEL_VSYS_SENSE     ADC_CHANNEL_5

// VSYS comp, COMP1_INP
#define VSYS_COMP_GPIO_PORT GPIOB
#define VSYS_COMP_PIN LL_GPIO_PIN_1 // PB1
#define EXTI_LINE_VSYS_COMP         LL_EXTI_LINE_21

// PGOOD. Input
#define PGOOD_GPIO_PORT GPIOF
#define PGOOD_PIN LL_GPIO_PIN_1 // PF1-OSC_OUT

// Fault LED. Output via TIM20_CH2 (AF6)
#define LED_FAULT_GPIO_PORT GPIOC
#define LED_FAULT_PIN LL_GPIO_PIN_2 // PC2

// Frontpanel button (input pullup) / encoder (input)
#define ENCODER_GPIO_PORT GPIOA
#define ENCODER_BUTTON_PIN LL_GPIO_PIN_5 // PA5
#define ENCODER_A_PIN LL_GPIO_PIN_6      // PA6 TIM3_CH1 (AF2)
#define ENCODER_B_PIN LL_GPIO_PIN_7      // PA7 TIM3_CH2 (AF2)
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

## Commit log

2024-12-23 Blink the onboard LED every time serial comms are detected.
2024-12-26 Fix center voltage calculation.
2025-01-07 Update capacitors to 25v in BOM
2025-01-15 Bump to 0.5, increase carrier freq to 2000, adjust current limits.
    Current limit increased from 1 to 1.2 amps, about 0.03 amps net increase
    with default tau value.
2025-01-15 Slightly adjust minimum resistance and inductance
2025-01-17 Split up BOM into different page.
2025-02-20 BOM improvements
2025-02-20 Increase current noise, voltage and temperature limits.
    [config.h]
2025-02-20 Decrease minimum resistance from 0.8 to 0.7
2025-02-26 Fix typo in BOM
2025-03-12 Tweak timing/ADC code
    - Increase PWM freq from 38k to 50k. New code can handle up to 74k
    - Read internal vref and chip temperature
    - Use oversampling for shunts
    - Minimum off time measured again
2025-04-24 Various fixes
    - Add COMP for monitoring VSYS on max22213 shield
    - Fix memory corruption issue in 3/4p model
    - Tweak learning rate on ESC1
    - Tweak some prints
    [fourphase_model.cpp, main.cpp]
2025-04-24 Adjust prints
2025-07-01 Add support for AS5311 sensor on V3
2025-07-08 Check for AS5311 sensor errors
    [as5311.cpp]
2025-07-08 Blink the LED on the G-431B-ESC1 when frame is received.
2025-07-12 Improve error detection for AS5311
    [as5311.cpp, as5311.h]
2025-07-29 Fix calibration scaling in three-phase.
    This bug causes the box to output stronger signals than intended
    when using large calibration parameters, making the safety limits
    quite likely to trigger.
2025-08-19 Expand voltage range on B-G431B-ESC1
    Some people reported problems with over-voltage, this appears to be
    caused by backpowering the 5v usb through the 12v adapter, causing
    analog errors that appear to be mostly harmless.
    [config_g431b_esc1.h]
2025-11-27 Add BOM and assembly guide for V4.
2025-11-27 Improve V4 BOM (battery)
2025-11-27 Update BOM, assembly and software installation for V4
2025-11-27 Simplify battery / vsys uvlo management
2025-11-27 Improve performance of battery statistics
2025-11-27 Fix math error in log
    [main_focstim_v3.cpp]
2025-11-27 fix typo in power manager
2025-11-27 Power optimization: disable drivers during downtime between pulses.
    for 70hz low pulse width threephase signal, this saves about 50mW.
2025-11-27 Remove support for FOC-Stim V3 and nucleo shield
    As recent changes most likely broke these boards in various ways
    and I have not tested them in a while.
    [main_focstim_v3.cpp, protobuf_api.cpp]
2025-11-27 Add more links to BOM
2025-11-27 Small code cleanup and increase default voltage for V4 to 22v
2025-11-27 Small refactor, no functional change intended.
    Replace some functions in foc_utils with <algorithm>
    Split up fourphase_model functionality in separate functions
    [bsp_g473re_focstim_v4.cpp, fourphase_model.cpp]
2025-11-27 Improve BOM for V4
2025-11-27 Modify case on filename for building on github actions
2025-11-28 Update assembly guide for V4.1 board
2025-11-28 Add images to BOM
2025-11-29 Add 3D files for V4
    [assembly fixture.step, assembly fixture.stl, battery sled.step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]
2025-12-01 Add a self-test for the current sensors.
2025-12-07 Improve assembly guide and BOM
2025-12-10 Add support for LSM6DSOX sensor
    accelerometer + gyroscope
2025-12-14 Increase the temperature limit on FOC V4 to 60c
2025-12-16 Add note about 3D printing seam alignment.
2025-12-24 Detect and prevent I2C bus hangs from the ESP32.
    [config_g473re_focstim_v4.h, esp32.cpp, imu.cpp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]
2025-12-24 Adjust IMU parameters
2025-12-24 Change minimum carrier frequency to 300Hz and set maximum pulse width to 35ms
2025-12-27 Add start/stop commands for LSM6DSOX IMU
2026-01-03 Change LCSC sourcing link for 2.0mm connectors
2026-01-07 Add support for sparkfun pressure sensor
2026-01-08 Adjust rear panel for V4.2 PCB
    [rear panel - 0.0mm clearance.step, rear panel - 0.0mm clearance.stl, rear panel - 0.1mm clearance.step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]
2026-01-12 Add schematics and gerbers for V4.2
    [BOM_FOC-Stim-v4.2_frontpanel.csv, BOM_FOC-Stim-v4.2_mainboard.csv, PickAndPlace_FOC-Stim-v4.2_frontpanel.csv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]
2026-01-13 Add 3d files for nintendo switch leg strap.
    [switch clip.step, switch clip.stl]
2026-01-21 Added 3D files for rear panel with expansion header
    [rear panel exp - 0.0mm clearance.step, rear panel exp - 0.0mm clearance.stl, rear panel exp - 0.1mm clearance.step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]
2026-01-22 Add docs for AS5311 sensor.
    Images by edger477
2026-01-24 Update docs for AS5311 sensor
    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
2026-02-10 Increase PCB rail clearance from 0.2mm to 0.3mm
    [case.step, case.stl]
2026-02-10 Add note about fuel gauge programming in assembly guide.
2026-02-14 Improve resistance/current bookkeeping.
2026-02-14 fix max current stats
    [fourphase_model.cpp]
2026-02-15 rework four-phase code + api
    [main_focstim_v4.cpp, protobuf_api.cpp]
2026-02-15 Increase the current limit margin on V4 to 120mA pri / 18mA sec.
    While I take time to investiage a better fix
    [config_g473re_focstim_v4.h]
2026-02-16 Fix undervoltage protection when no battery is present.
    Because of race conditions in the DAC initialization,
    this could either result in self test failure or
    nonfunctional brownout protection.
2026-02-16 Remove debug code attached to pulse interval random
2026-02-23 Fix power statistics not including the 4th output.
    [main_focstim_v4.cpp]
2026-02-23 Refactor multiplication out of tight loop
    [fourphase_model.cpp]
2026-02-26 Greatly improve skin resistance model performance
2026-02-28 Implement device volume lock feature
    - rename potentiometer to device_volume in protobuf api
    - add api call to lock device volume
    - add api notifications for encoder button
    - refactor encoder handling out of BSP
    - show padlock icon on display when volume is locked
    - quick-turn overrides the lock
    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
2026-03-04 Move bootloader-check code earlier in setup.
    This prevents the extended erase command in the bootloader
    from hardfaulting the chip.
    Bump version to v1.2.2
    [main_focstim_v4.cpp]
2026-03-04 Add dynamic boost voltage + hardware utilization on V4
2026-03-04 Fix phase angle convergance.
    [fourphase_model.cpp, fourphase_model.h]
2026-03-09 Some tweaks to deadtime and ADC trigger delay
2026-03-10 Improve skin resistance estimation
2026-03-12 Fix small math error in skin resistance calculation
2026-03-16 Reduce sampling rate of VM_SENSE and VSYS_SENSE
    This is needed for upcoming PCB revision.
2026-03-20 Upload gerbers/schematics to board revision V4.3
    [BOM_FOC-Stim-v4.2_frontpanel.csv, BOM_FOC-Stim-v4.2_mainboard.csv, BOM_FOC-Stim-v4.3_frontpanel.csv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]
2026-04-14 Add 'reduction in center' 4p calibration axis
2026-04-14 Increase the maximum body current to 200mA
2026-05-25 Fix issues using the restim firmware flasher
    Only the first 8 bytes out of every 256 bytes of flash
    be written. Not sure why.
    [bootloader.cpp]
2026-09-23 Bump version to 2.0.0 (+ changes)
    Modify three-phase api to use calibration a/b/c instead of updown/leftright
    Remove limit on pulse frequency, restrict pulse pause duration to 5ms
2026-10-26 Add version info for esp32
2026-10-27 Do not request the esp32 version.
    This causes hangs with older versions of the esp32 firmware.
